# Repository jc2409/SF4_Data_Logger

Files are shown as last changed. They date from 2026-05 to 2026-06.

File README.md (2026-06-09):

# SF4 Smart Guitar Amp

SF4 is a hybrid guitar-effect amplifier built around a real analog input/output
path, an Arduino Uno DSP firmware, and a browser-based host app. The system lets
a player control the amp manually or ask for a sound in natural language; the host
turns that request into validated firmware parameters and sends them to the board.

The current implementation has three working layers:

1. Analog hardware for guitar-level signal conditioning, optical gain control, ADC
   input conditioning, and PWM audio reconstruction.
2. Arduino firmware for real-time DSP, automatic gain control, serial commands, and
   telemetry.
3. A FastAPI + React web app with sliders, live telemetry, tuner display, OpenAI chat,
   and Whisper-based voice input.

See [docs/SF4_Interim_Report.pdf](docs/SF4_Interim_Report.pdf) for the project report
context. The current host setup details live in [src/host/README.md](src/host/README.md).

## System Overview

```text
Guitar
  -> analog input buffer and 2.5 V bias
  -> optically controlled analog gain stage
  -> anti-aliasing low-pass filter
  -> Arduino A0 ADC
  -> Uno DSP firmware
  -> 62.5 kHz PWM audio on pin 10
  -> two-stage RC reconstruction filter and output coupling
  -> amp / line input / high-impedance headphones

Browser UI
  -> FastAPI host
  -> serial P frames to Arduino
  <- T telemetry frames from Arduino
  -> OpenAI chat and Whisper STT when enabled
```

The host falls back to a mock serial link when no board is connected, so the web app
and LLM/voice flow can still be demonstrated without hardware.

## Final Analog Circuit

The analog path is designed for a single 5 V system while preserving the AC guitar
signal around a 2.5 V virtual ground.

**Input and biasing**

- The guitar enters a high-impedance buffered input so passive pickups are not loaded.
- The signal is AC-coupled, then biased at about 2.5 V so the Arduino ADC can read the
  waveform inside its 0-5 V range.
- A buffered 2.5 V reference is used as the analog midpoint for the signal chain.

**Optical variable gain stage**

- The firmware drives an optocoupler LED from PWM pin 9 / OC1A.
- The optocoupler LDR changes the analog gain without putting a noisy digital control
  signal directly into the audio path.
- In automatic mode, firmware rides this gain gently based on measured output peak:
  loud signals are attenuated, quiet played signals are boosted, and silence drifts
  back to the resting gain.

**ADC conditioning**

- The post-gain audio is low-pass filtered before A0 to reduce content above the ADC
  Nyquist frequency.
- The firmware samples A0 at about 9.6 kHz, so the practical audio bandwidth is guitar
  focused rather than hi-fi full range.

**PWM audio output**

- The Arduino outputs processed audio as 8-bit Fast PWM on pin 10 / OC1B at 62.5 kHz.
- The final reconstruction filter is two passive RC low-pass stages with a buffer between
  them: 2.2 kOhm + 15 nF per stage, giving a corner near 4.8 kHz per pole.
- The buffer-between-poles topology is intentional. It avoids the high-frequency carrier
  feedthrough and slew problems seen with a slow-op-amp Sallen-Key attempt.
- The output is AC-coupled through a 10 uF capacitor with a 100 kOhm pulldown, removing
  the 2.5 V bias while keeping the guitar low end intact.
- The output is intended for a high-impedance line/aux input or similar load, not for
  directly driving a low-impedance speaker.

The PWM output-stage debugging and component choices are documented in
[src/PWM_Audio_Passthrough/DESIGN_NOTES.md](src/PWM_Audio_Passthrough/DESIGN_NOTES.md).

## Firmware

The current firmware is [src/DSP_Pipeline/DSP_Pipeline.ino](src/DSP_Pipeline/DSP_Pipeline.ino).
It targets an Arduino Uno R3 / ATmega328P.

**Timing and I/O**

- ADC input: A0, free-running, prescaler 128, about 9.6 kHz sample rate.
- Audio output: Timer1 8-bit Fast PWM on pin 10 / OC1B, 62.5 kHz carrier.
- VGA output: Timer1 PWM on pin 9 / OC1A, 0-255 duty value.
- Serial: 115200 baud.
- Audio processing runs in the `ADC_vect` interrupt, one sample at a time.

**Effects**

The firmware runs exactly one effect mode at a time:

| ID | Effect | Implemented behavior |
| --- | --- | --- |
| `0` | Clean | Transparent passthrough. |
| `1` | Overdrive | Pre-gain followed by hard clipping; `drive` range 1-511. |
| `2` | Delay | Single circular-buffer echo, up to 512 samples, about 53 ms at 9.6 kHz. |
| `3` | Chorus | Triangle-LFO modulated short delay with 50/50 dry/wet mix. |
| `4` | Reverb | Ten-tap feedback network; feedback should stay below about 205 for stability. |
| `5` | Tuner | Clean passthrough while the main loop runs AMDF pitch detection. |

The shared audio buffer is 512 `int8_t` samples. Delay, chorus, reverb, and tuner all
reuse that memory so the firmware fits within the Uno SRAM budget.

**Serial control protocol**

The host sends an atomic all-parameters frame:

```text
P,<effect>,<drive>,<delayLen>,<feedback>,<mix>,<depth>,<rate>,<autoVGA>,<gain>
```

Ranges enforced by the firmware and host models:

| Field | Range | Meaning |
| --- | --- | --- |
| `effect` | 0-5 | Clean, overdrive, delay, chorus, reverb, tuner. |
| `drive` | 1-511 | Overdrive gain/clipping intensity. |
| `delayLen` | 1-512 | Delay tap distance in samples. |
| `feedback` | 0-255 | Delay repeats or reverb decay. |
| `mix` | 0-255 | Wet level for delay/reverb. |
| `depth` | 1-48 | Chorus modulation depth in samples. |
| `rate` | 1-20 | Chorus LFO phase increment. |
| `autoVGA` | 0 or 1 | Enable automatic analog gain control. |
| `gain` | -1 or 0-255 | `-1` keeps/uses auto mode; 0-255 sets manual VGA PWM. |

The board reports telemetry every 100 ms:

```text
T,<effect>,<peak>,<vga>,<clip>,<rxErr>,<freqDeciHz>
```

`freqDeciHz` is only nonzero in tuner mode and is reported as Hz x 10. The host turns
this into the tuner display against standard guitar tuning.

More firmware-specific notes are in [src/DSP_Pipeline/README.md](src/DSP_Pipeline/README.md).

## Web App

The web app lives in [src/host](src/host). It is a single FastAPI backend serving a
React/Vite frontend.

**Backend responsibilities**

- Own the real `SF4Link` serial connection, or use `MockLink` when hardware is absent.
- Keep the authoritative `AmpParams` state.
- Validate and clamp all values before they reach the firmware.
- Serve `GET /api/state`, `POST /api/params`, `POST /api/chat`, `POST /api/transcribe`,
  and `GET /api/telemetry`.
- Load `.env` for serial port, OpenAI proxy, CA bundle, model names, and server host/port.

**Frontend responsibilities**

- Manual amp controls for effect selection and the relevant parameters.
- Live telemetry and connection state.
- Tuner UI driven by firmware pitch telemetry.
- Chat panel for natural-language tone requests.
- Voice input flow using the wake phrase `hey amp`, browser microphone capture, Whisper
  transcription, and then the same chat/tone path as typed messages.

**Tone engine**

- OpenAI is the default provider when `OPENAI_API_KEY` is set.
- `OPENAI_BASE_URL` supports enterprise proxy routing, including the Arm proxy URL.
- `OPENAI_CA_BUNDLE` lets Python trust the enterprise TLS certificate without disabling
  verification.
- `OPENAI_CHAT_MODEL` currently defaults to `gpt-5.5`; change it in `.env` if the proxy
  reports no regional capacity for that model.
- Anthropic remains available as a fallback with `SF4_LLM_PROVIDER=anthropic` and
  `ANTHROPIC_API_KEY`.

The LLM is not allowed to send arbitrary firmware strings. It can only call the structured
`set_amp_params` tool, and those values are validated by the host before the serial frame
is emitted.

## Running The Web App

From the repository root:

```bash
cd src/host
make env
# edit .env: set OPENAI_API_KEY, OPENAI_BASE_URL if required, and SF4_PORT if needed
make install
make run
```

Then open `http://127.0.0.1:8000`.

Useful setup commands:

```bash
make port          # list serial devices and mark likely Arduino ports
make set-port      # write detected board to .env as SF4_PORT=...
make serial-perms  # temporary Linux permission fix for the selected SF4_PORT
make doctor        # print local Python/Node/npm/OpenAI/SF4_PORT status
make web-dev       # frontend hot reload on :5173 while make run serves the API
make flash         # compile/upload firmware with arduino-cli
```

Dependencies and configuration are documented in [src/host/README.md](src/host/README.md).
The Python dependency lists are [src/host/requirements.txt](src/host/requirements.txt) and
[src/host/pyproject.toml](src/host/pyproject.toml); frontend dependencies are in
`src/host/web/package.json` and `src/host/web/package-lock.json`.

## Repository Layout

```text
docs/                         project handouts, order sheet, interim report
src/DSP_Pipeline/             current Arduino DSP firmware and firmware README
src/PWM_Audio_Passthrough/    PWM output-stage prototype and final design notes
src/host/                     FastAPI backend, React frontend, Makefile, host docs
schematics/                   analog design and LTSpice material
```

## Current Limitations

- Audio quality is constrained by the Arduino Uno ADC rate, 8-bit PWM output, SRAM, and
  simple reconstruction filter. This is a working guitar-effect prototype, not a studio
  audio interface.
- Only one firmware effect runs at a time.
- The output stage expects a high-impedance input/load.
- Voice transcription and chat depend on the selected OpenAI model being available through
  the configured proxy and VPN policy.

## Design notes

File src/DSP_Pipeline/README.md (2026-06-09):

# SF4 Real-Time Guitar DSP Pipeline — Firmware

Arduino Uno R3 (ATmega328P) firmware implementing a real-time, **selectable
multi-effect** guitar DSP — **Clean / Overdrive / Delay / Chorus / Reverb** — plus
a **Tuner** mode that detects the played string's pitch, all with a serial command
interface for live parameter control.

Sketch: [`DSP_Pipeline.ino`](DSP_Pipeline.ino)

> **Note:** an earlier version of this firmware (and this README) ran a *cumulative*
> `Clip → Biquad EQ → Delay` pipeline driven by an `S,...` frame at 19230 Hz. That is
> obsolete. The current firmware selects **one** effect at a time and runs the ADC at
> **~9615 Hz**. The host software (`../host/`) targets this current protocol.

---

## Signal path

```
guitar (biased 2.5 V) ─▶ A0 ─▶ ADC (free-running, 10-bit, ~9.615 kHz, prescaler 128)
                                  │
                                  ▼  ISR(ADC_vect)   ← one DSP tick per sample
                    one of: Clean | Overdrive | Delay | Chorus | Reverb
                                  │
                                  ▼
                    OCR1B (8-bit, 62.5 kHz Fast PWM, pin 10)
                                  │
                                  ▼
                    RC reconstruction filter ─▶ analog audio out
```

- **Input**: guitar AC-coupled and biased to 2.5 V on A0; ADC reads 0..1023 (512 = silence).
- **Output**: pin 10 (OC1B), 8-bit Fast PWM, 62.5 kHz carrier, smoothed by an external RC filter.
- **Optocoupler**: pin 9 (OC1A), same Timer1, sets the analog VGA gain via the LED/LDR.
- **Sample rate**: ADC prescaler 128 → ~9615 Hz (Nyquist 4.8 kHz, matching the anti-alias LPF).
  Delay/reverb taps are `t = samples / 9615 Hz`; the 512-sample buffer holds ~53 ms.

---

## Effects

All processing is **fixed-point** (no float in the ISR). Samples are carried as
signed values centred on 0 (range −512..+511). **One effect is active at a time**
(selected with `e`); switching effects clears the audio ring buffer.

| ID | Effect | What it does | Parameters |
|----|---|---|---|
| 0 | **Clean** | Transparent passthrough | — |
| 1 | **Overdrive** | Pre-amplify then hard-clip | `thresh` 1..511 (drive: 16=breakup, 180=rock, 480=metal) |
| 2 | **Delay** | Single echo with feedback (~53 ms max) | `delayLen` 1..512, `feedback` 0..255, `mix` 0..255 |
| 3 | **Chorus** | Triangle-LFO modulated short delay, 50/50 dry/wet | `depth` 1..48, `rate` 1..20 |
| 4 | **Reverb** | Ten-tap feedback network | `feedback` 0..255 (keep < 205), `mix` 0..255 |
| 5 | **Tuner** | Clean passthrough + fundamental-pitch detection (reported via telemetry) | — |

**Delay/reverb timing**: `t = samples / 9615 Hz`. The 512-sample `int8` line holds ~53 ms.

### Tuner

Selecting **Tuner** (effect 5) passes the signal through clean while detecting the
played string's fundamental frequency and reporting it in the `freq` telemetry
field (deci-Hz; `0` = no pitch). The host UI shows the detected pitch against the
six standard-tuning strings (E2 A2 D3 G3 B3 E4) with a flat↔sharp cents needle.

- **Method**: **AMDF** (Average Magnitude Difference Function) over the audio ring
  buffer, searching lags ~24..128 samples (≈75–400 Hz). The deepest dip is the
  period; **parabolic interpolation** around it recovers sub-sample resolution —
  essential for the high strings, where one whole-sample lag step is tens of cents
  at 9615 Hz. A peak-amplitude gate suppresses readings on silence.
- **Where it runs**: in `loop()` (every ~150 ms), **not** the ISR, and only while
  effect 5 is active — so it costs nothing in the other modes. It works on a frozen
  copy of the most recent samples, since the ISR keeps overwriting the live ring
  during the (tens-of-ms) computation.

---

## Serial command interface

`115200 baud`, one command per line. The parser buffers a full line then parses
it (robust to `\n` / `\r\n` / no line ending).

| Command | Example | Effect |
|---|---|---|
| `e<0..5>` | `e1` | Select effect (0=clean 1=overdrive 2=delay 3=chorus 4=reverb 5=tuner) |
| `c<1..511>` | `c180` | Overdrive drive (thresh) |
| `d<1..512>` | `d400` | Delay length in samples |
| `f<0..255>` | `f190` | Delay/reverb feedback / decay |
| `m<0..255>` | `m220` | Delay/reverb wet mix |
| `r<1..48>` | `r24` | Chorus depth |
| `s<1..20>` | `s8` | Chorus LFO rate |
| `v<0\|1>` | `v1` | Auto-VGA on/off |
| `g<0..255>` | `g20` | Manual VGA gain (OCR1A); turns auto-VGA off |
| `x` | `x` | Bypass (clean passthrough) |
| `P,...` | `P,1,180,400,190,220,24,8,1,-1` | Atomic set-all frame (host link) |

The single-letter commands are for manual testing; the host uses the `P` frame.

> **Note**: a delay/echo is only audible on *transient* material (real guitar,
> plucks, music). On a steady sine it just produces inaudible comb filtering.

## Two-way host protocol (MCU ↔ PC)

Structured parameters in, status telemetry out. The host applies a whole preset
atomically with one `P` frame and reads `T` telemetry back:

```
PC -> MCU : P,<effect>,<drive>,<delayLen>,<feedback>,<mix>,<depth>,<rate>,<autoVGA>,<gain>\n
MCU -> PC : T,<effect>,<peak>,<vga>,<clip>,<rxErr>,<freq>\n      (emitted ~10 Hz)
```

- **`P` frame** — sets the entire parameter bank in one `cli/sei` section (no
  transient old+new mix), clearing the audio buffer on effect change. `gain` field
  `< 0` leaves the VGA untouched and honours the `autoVGA` flag; `>= 0` sets a manual
  gain and turns auto-VGA off. Malformed frames are rejected and counted in `rxErr`.
- **`T` telemetry** — `effect` (active effect ID), `peak` (max |output| since last
  report — a VU meter), `vga` (current `OCR1A`), `clip` (clipped since last report),
  `rxErr` (malformed-frame count), `freq` (detected fundamental in **deci-Hz** —
  Hz×10 — in tuner mode, else `0`).
  > The `freq` field is appended; the host parser accepts both the 6-field
  > (pre-tuner) and 7-field frames, so older firmware still parses.

### Host software

The full interface is the **web app** in [`../host/`](../host/) (FastAPI + LLM tone
engine + browser dashboard). For bench testing without a browser:

```bash
cd ../host && uv sync          # or: pip install -e .
python sf4_serial.py --demo overdrive
python sf4_serial.py --effect reverb --feedback 190 --mix 220
```

It builds a validated `AmpParams`, serialises the `P` frame, sends it, then prints
parsed `T` telemetry as a live meter.

---

## Architecture / timing

- **Timer1** — Mode 5, 8-bit Fast PWM, no prescaler → **62.5 kHz** carrier on
  OC1A (pin 9) and OC1B (pin 10). Pure hardware; **no overflow ISR**.
- **ADC** — free-running, `/128` prescaler → ~**9615 Hz** sample rate, with the
  conversion-complete interrupt enabled (Nyquist 4.8 kHz, matching the anti-alias LPF).
- **`ISR(ADC_vect)`** — the single DSP tick: reads `ADC`, runs `processEffect`,
  writes `OCR1B = result >> 2` (10-bit → 8-bit). Fires once per sample (~9615 Hz).
  Reading `ADC` clears `ADIF` and the ADC auto-restarts, so no flag handling is needed.
- `OCR1B` is **double-buffered** by the PWM hardware (latches at carrier BOTTOM),
  so updating it at 9615 Hz while the carrier runs at 62.5 kHz is glitch-free.
- **Parameter bank** — one `volatile Params` struct (`P`). `loop()` updates it
  atomically inside `noInterrupts()/interrupts()` (field-wise copies, because a
  `volatile` struct can't use the implicit copy ctor), so the ISR never reads a
  half-written parameter set.

---

## Testing & operation notes

### Reading the telemetry (`T,effect,peak,vga,clip,rxErr,freq`)
- **`effect`** — active effect ID (0–5).
- **`peak`** — loudest **post-effect** sample since the last report (~100 ms), as a
  centred magnitude. This is a live VU/level meter; it wobbles ±1 on a steady signal
  (normal). It reflects what the listener actually hears (the AGC rides off it), so
  it tracks the output, not the raw input.
- **`vga`** — current `OCR1A` (the optocoupler LED duty / analog gain); static until
  changed or moved by auto-VGA.
- **`clip`** — 1 if the signal hit the clip threshold in that window, else 0.
- **`rxErr`** — malformed-frame count; should stay 0 (link health).
- **`freq`** — detected fundamental in **deci-Hz** (Hz×10) in tuner mode, else `0`.

### Startup transient is expected (and repeats every run)
Opening the serial port toggles **DTR, which hardware-resets the Uno** — so every
`sf4_serial.py` run reboots the board from scratch. At boot `OCR1A = 20`
(resting VGA gain), then the first host `P` frame confirms auto-VGA mode; the optocoupler LDR
settles slowly (tens–hundreds of ms), so `peak` shows a brief spike that decays
(e.g. `197 → 6`). Harmless — it's the analog gain settling, not a glitch. Ignore
the first few telemetry lines, or add gain smoothing in firmware to remove it.

### What a sine-wave input can test
| Stage | Sine test | Method |
|---|---|---|
| Passthrough | ✅ | `x`; output = input, biased 2.5 V |
| Clipping (overdrive) | ✅ | drive above threshold → flat-topped wave + odd harmonics |
| Aliasing | ✅ | feed f > Nyquist (4.8 kHz) → watch it fold back |
| Delay comb | ✅ | sweep → notches every `FS/d` Hz |
| Chorus sweep | ✅ | slow LFO → pitch/comb notches drift up and down |
| Delay/reverb *echo* | ❌ | needs transients (real guitar / music) |
| Tuner | ✅ | feed a known tone → check `freq` (deci-Hz) telemetry |

### Signal levels (real guitar vs the VGA)
A raw passive guitar is weak and dynamic (~0.1–0.7 Vpp typical, peaks to ~1–1.5 Vpp
on hard strums, decaying fast) — it does **not** sit at line level. The optocoupler
**VGA (gain) is what boosts it** up to where `peak` crosses the clip threshold, so
`gain` (drive) + `clip_threshold` together behave like a pedal's Drive knob. On the
bench, ~1 Vpp from the generator is a *test* level to force clipping. Distortion is
naturally touch-sensitive: loud attack clips, decaying note cleans up.

---

## Implementation notes

### DSP runs in `ADC_vect`, not a timer ISR
The single DSP tick lives in **`ISR(ADC_vect)`** (~9615 Hz): it reads `ADC`, runs
`processEffect`, and writes `OCR1B`. The Timer1 overflow interrupt is left disabled
(`TIMSK1 = 0`) — the PWM carrier is pure hardware. Driving the DSP from the ADC
interrupt means it fires exactly once per sample, with no wasted firings.

### Atomic parameters from a `volatile` struct
`Params np = P;` / `P = np;` don't compile for a `volatile` struct, so `loop()`
copies fields one at a time inside `noInterrupts()/interrupts()`. This both satisfies
the compiler and makes parameter updates atomic — the ISR never sees a half-written
mix of old and new values, and switching effects clears the audio ring buffer.

### Robust serial parsing
The command parser **buffers a full line** then parses it with `atol` / `sscanf`,
tolerant of `\n`, `\r\n`, or no line ending. (An earlier `Serial.parseInt()` version
mis-read leftover `\r`/`\n` as `0`, e.g. `f160` → `feedback = 0`.) The board runs at
**115200 baud**; because the DSP no longer sits in a 62.5 kHz timer ISR, the USART RX
interrupt is serviced in time and there is no RX overrun.

### Two-way protocol (MCU ↔ PC)
The host applies a whole preset atomically with one **`P` frame** and reads **`T`
telemetry** back at ~10 Hz (`effect, peak, vga, clip, rxErr, freq`). The ISR tracks
`g_peak` / `g_clip` / `g_freqDeciHz`; `loop()` emits via `millis()`. The full
host-side link is the FastAPI web app in [`../host/`](../host/); `sf4_serial.py` is a
standalone CLI for bench testing the same `P`/`T` protocol.

---

## Recommended analog output stage

The PWM output needs an external reconstruction filter + buffer before any
external device. Drives high-impedance line inputs (Echo line-in, Sennheiser
Momentum 4 powered aux) directly — **no power amp needed**.

```
pin 10 ─[2-pole RC LPF: 2.2k / 15nF ×2]─ MCP6002 unity buffer ─ Rs 100Ω ─ Cout 10µF ─┬─ tip L ┐
                                                                                      ├─ tip R ┘ (tie, mono)
                                                                                     R 100k → GND
                                                                                      sleeve → GND
```

- **Use MCP6002** (rail-to-rail, single 5 V), **not** TL072 (needs ≥7 V).
- Because the MCP6002 is only 1 MHz GBW, **filter passively** (RC) and use the
  op-amp only as a buffer — do **not** put it in a Sallen-Key (it would leak the
  62.5 kHz carrier, like the LM358).
- Two RC poles give ~−40 dB at the carrier, removing the switching hash.
- `Cout` strips the 2.5 V DC bias; into a high-Z input the bass is preserved.

---

## Known limitations / potential issues

| Issue | Impact | Possible improvement |
|---|---|---|
| Hard-clip aliasing | Harsh "fizzy" distortion (folded harmonics) | Soft-clip lookup table; 2× oversampling |
| 8-bit PWM output | ~48 dB SNR; hiss on clean tones | Higher-res PWM; dithering |
| One effect at a time | No stacking (e.g. overdrive + delay) | Chain effects if CPU/SRAM allow |
| Delay/reverb ≤ ~53 ms | Slapback/short ambience, not long echo | External SRAM for a longer line |
| `int8` ring buffer | 2 LSBs dropped on stored samples | Wider buffer if SRAM allows |
| No parameter smoothing | Clicks on live LLM/host changes | Ramp parameters over a few ms |
| Free-running ADC jitter | Minor sample-timing noise | Timer-triggered ADC (needs a free timer) |
| 16 MHz AVR ceiling | Limited DSP headroom overall | Faster MCU for advanced effects |

---

## Status

Working lo-fi multi-effect demonstrator: selectable Clean / Overdrive / Delay /
Chorus / Reverb plus an AMDF Tuner, with live serial control **and a two-way MCU↔PC
link** (`P` params in, `T` telemetry out, at 115200). The FastAPI web app in
[`../host/`](../host/) drives this protocol from the browser, manual controls, and the
LLM tone engine; `sf4_serial.py` exercises the same link from the command line.

### Suggested next steps
- DSP quality: soft-clip lookup table (reduce overdrive aliasing), parameter/gain
  smoothing to remove clicks on live host changes.
- Longer delay/reverb via external SRAM, beyond the ~53 ms on-chip `int8` line.
- Build the MCP6002 analog output stage (above) for clean line-out.

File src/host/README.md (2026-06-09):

# SF4 Host - Backend, Voice UI, and Tone Engine

This directory contains the desktop/web host for the SF4 smart guitar amp. One
FastAPI process owns the serial link to the Arduino, keeps the authoritative amp
state, runs the OpenAI-first tone engine, serves the React dashboard, and exposes
JSON/SSE APIs for manual control, chat, voice transcription, and telemetry.

## Layout

```text
app/
  main.py         FastAPI app: /api/* endpoints, static UI serving, app lifetime
  models.py       AmpParams, telemetry, chat schemas, firmware value ranges
  serial_link.py  SF4Link hardware bridge, MockLink fallback, port autodetect
  tone_engine.py  OpenAI/Anthropic tone engine with set_amp_params tool use
  openai_client.py OpenAI client setup for API key, proxy URL, and CA bundle
  devtools.py     Makefile helpers for serial-port detection and config checks
  static/         built React UI generated by make web-build, gitignored
web/              React + Vite frontend source
sf4_serial.py     CLI bench-test tool for sending P frames and reading telemetry
Makefile          setup, build, run, serial, and firmware automation
requirements.txt  pip dependency list, kept in sync with pyproject.toml
pyproject.toml    Python project metadata and dependencies
.env.example      local configuration template; copy to .env
```

The React source lives in `web/`. `make web-build` compiles it into `app/static/`,
which FastAPI serves at `http://127.0.0.1:8000` by default.

## Quick Start

```bash
cd src/host
make env
# edit .env and set OPENAI_API_KEY, OPENAI_BASE_URL if using the Arm proxy,
# OPENAI_CA_BUNDLE if your machine needs the company CA, and SF4_PORT if needed
make install
make run
```

Open `http://127.0.0.1:8000`.

`make run` also installs Python dependencies and builds the UI on first run if the
built frontend is missing. Use `Ctrl+C` to stop Uvicorn.

## Make Targets

| Target | Purpose |
| --- | --- |
| `make help` | Print the available commands. |
| `make env` | Create `.env` from `.env.example` if it does not exist. |
| `make py-install` | Install backend dependencies with `uv sync` when `uv` is available, otherwise create `.venv` and run `pip install -r requirements.txt`. |
| `make web-install` | Install frontend dependencies with `npm ci --include=dev --no-audit --no-fund --progress=false`. |
| `make web-build` | Build the React/Vite UI into `app/static/`. |
| `make install` | Run backend install, frontend install, and frontend build. |
| `make run` | Start FastAPI on `HOST:PORT`, building the UI first if missing. |
| `make dev` | Same as `make run`, but with Uvicorn `--reload`. |
| `make web-dev` | Start Vite hot reload on port 5173; `/api` is proxied to FastAPI on port 8000. |
| `make port` | List detected serial ports and mark likely Arduino ports with `*`. |
| `make set-port` | Write the first likely Arduino port into `.env` as `SF4_PORT=...`. |
| `make serial-perms` | Temporarily run `sudo chmod a+rw $(SF4_PORT)` if Linux denies access to the board. |
| `make doctor` | Print Python, Node, npm, host URL, serial setting, and whether OpenAI settings are present. |
| `make cli ARGS="--demo overdrive"` | Test the serial link without the browser. |
| `make flash` | Compile and upload `../DSP_Pipeline` with `arduino-cli`. |
| `make clean` | Remove `.venv`, Python caches, and built UI output. |

For frontend-only development, use two terminals:

```bash
make run        # terminal A: FastAPI on :8000
make web-dev    # terminal B: Vite on :5173 with /api proxying
```

## Dependencies

System tools:

- Python 3.11 or newer.
- Node.js and npm for the React/Vite frontend.
- `arduino-cli` only if you want `make flash` to compile and upload firmware.
- Linux serial access to the board, either through group membership or `make serial-perms`.

Python packages are declared in both `requirements.txt` and `pyproject.toml`:

- `fastapi`, `uvicorn[standard]`: web server and API runtime.
- `pyserial`: USB serial link to the Arduino.
- `openai`, `httpx`: OpenAI chat/STT client, enterprise proxy, and CA-bundle support.
- `anthropic`: optional fallback provider.
- `pydantic`: API and firmware parameter validation.
- `python-dotenv`: `.env` loading.
- `python-multipart`: browser audio upload support for `/api/transcribe`.

Frontend packages are managed by `web/package.json` and `web/package-lock.json`.
Use `make web-install` or `make install`; do not use `npm install --omit=dev`, because
Vite is a dev dependency required for building.

## Configuration

Copy `.env.example` to `.env` with `make env`. `.env` is gitignored and should hold
machine-specific settings and API keys.

| Variable | Default | Meaning |
| --- | --- | --- |
| `SF4_LLM_PROVIDER` | `openai` | Tone engine provider: `openai` or `anthropic`. |
| `OPENAI_API_KEY` | blank | Required for OpenAI chat and Whisper transcription. |
| `OPENAI_CHAT_MODEL` | `gpt-5.5` | Chat model used for tone generation. Change this if the proxy has no capacity for that model. |
| `OPENAI_BASE_URL` | OpenAI default | Set to the enterprise proxy URL, for example `https://openai-api-proxy.geo.arm.com/api/providers/openai/v1`. |
| `OPENAI_CA_BUNDLE` | Arm root CA path | Optional CA bundle path for enterprise TLS verification. |
| `OPENAI_TRANSCRIBE_MODEL` | `whisper-1` | Speech-to-text model used by `/api/transcribe`. |
| `ANTHROPIC_API_KEY` | blank | Optional fallback when `SF4_LLM_PROVIDER=anthropic`. |
| `SF4_MODEL` | `claude-haiku-4-5` | Anthropic model name for the fallback provider. |
| `SF4_PORT` | auto-detect | Serial device, for example `/dev/ttyACM0`. Use `make port` or `make set-port`. |
| `HOST` / `PORT` | `127.0.0.1` / `8000` | Uvicorn bind address used by `make run` and `make dev`. |

For the Arm enterprise OpenAI proxy, the relevant `.env` entries are usually:

```bash
OPENAI_API_KEY=your_key_here
OPENAI_BASE_URL=https://openai-api-proxy.geo.arm.com/api/providers/openai/v1
OPENAI_CA_BUNDLE=/usr/local/share/ca-certificates/ARM-Enterprise-PKI-Root-CA.crt
OPENAI_CHAT_MODEL=gpt-5.5
OPENAI_TRANSCRIBE_MODEL=whisper-1
```

If you see `data_residency_mismatch` or `No available capacity`, the proxy rejected the
selected model in that region. Change `OPENAI_CHAT_MODEL` to a model that your proxy
supports and restart `make run`.

## API

| Endpoint | Purpose |
| --- | --- |
| `GET /api/state` | Current amp parameters, serialized with the effect name. |
| `POST /api/params` | Apply a full manual `AmpParams` update. |
| `POST /api/chat` | Run one tone-engine turn; may call `set_amp_params` and update the board. |
| `POST /api/transcribe` | Upload browser audio and return Whisper text. |
| `GET /api/telemetry` | Server-Sent Events stream of board telemetry at about 10 Hz. |

The app falls back to `MockLink` when no Arduino is available, so the UI, chat, and
voice flow can be tested without hardware. Manual changes still update the shared app
state, but no serial frames are sent to a board.

## Troubleshooting

- `vite: not found`: run `make web-install` or `make install`. If npm used omitted dev dependencies, run `npm --prefix web ci --include=dev --no-audit --no-fund --progress=false`.
- Npm hangs on VPN: check whether company VPN/proxy rules block `registry.npmjs.org`; disconnecting VPN or configuring npm proxy may be required.
- `Permission denied: /dev/ttyACM0`: run `make set-port`, then `make serial-perms`, or add your user to the Linux dialout group and log out/in.
- `Chat is unavailable`: set `OPENAI_API_KEY` or configure the Anthropic fallback, then restart the server.
- `Transcription error`: check `OPENAI_API_KEY`, `OPENAI_BASE_URL`, `OPENAI_CA_BUNDLE`, and VPN/proxy connectivity.
- Browser says microphone denied: allow microphone access for `http://127.0.0.1:8000` in the browser site settings, then reload.

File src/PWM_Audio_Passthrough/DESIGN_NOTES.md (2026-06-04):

# PWM Audio Passthrough — Design & Debug Notes

A record of the debugging session that took the PWM audio output from "looks like
raw PWM on the scope" to a clean, full-range guitar signal. Covers the filter
diagnosis, the component-value fixes, and the firmware change to a 62.5 kHz carrier.

---

## 1. The system

- **Arduino Uno R3**, guitar signal biased to 2.5 V into **A0** (ADC 0..1023, 512 ≈ silence).
- **Timer1 Fast PWM** drives two independent outputs:
  - **Pin 10 (OC1B)** → audio, through a low-pass filter → audio jack.
  - **Pin 9 (OC1A)** → optocoupler LED (VGA gain stage), set over serial.
- Audio recovered by averaging the PWM (low-pass) then AC-coupling out (high-pass).

Output analog chain (KiCad): `pin 10 → R12 → C7 (low-pass) → LM358 (U2B) → C8 → R13 (high-pass) → AudioJack`.

---

## 2. The symptom

On the PicoScope:
- **Blue (A)** = analog input at A0: a clean sine (300/600/800 Hz test tones), biased at 2.5 V.
- **Red (B)** = "recovered" output: a dense band of pulses, **cycle time 64.00 µs → 15.625 kHz**.

The red trace never looked like the blue sine. The user asked why.

### Why red ≠ blue (the concept)
The raw PWM is a **two-level carrier** (≈0 V or ≈5 V) switching at 15.625 kHz. The
audio is encoded in the **duty cycle / pulse width**, not the instantaneous voltage:

```
blue high (3.5V)  ->  OCR1B large  ->  pulses WIDE  (more time at 5V)
blue low  (2.0V)  ->  OCR1B small  ->  pulses NARROW (more time at 0V)
```

You recover the sine by taking the **running average** of the PWM — which is exactly
what the RC low-pass does. So red ≠ blue *before* the filter is expected and correct.

---

## 3. Root cause #1 — the low-pass filter wasn't filtering

A low-pass needs **both** the series resistor **and** the shunt cap to ground. R12
alone does nothing (the op-amp input is high-impedance, so almost no drop across R12).
C7 is the part that averages the pulses.

The cutoff:

$$f_c = \frac{1}{2\pi R C}$$

The board had **R12 = 1k** and **C7 marked `103` = 10 nF** (NOT the assumed 220 nF):

$$f_c = \frac{1}{2\pi \cdot 1000 \cdot 10\text{n}} \approx 15.9\ \text{kHz}$$

That sits **right on top of the 15.625 kHz carrier** → only −3 dB attenuation → the
carrier passes straight through. Time-constant view: `τ = R12·C7 = 10 µs`, but the
PWM period is `64 µs`, so the cap fully tracks each pulse instead of averaging.

### Capacitor code reminder (value in picofarads)
| Code | Value | Notes |
|---|---|---|
| `103` | 10 nF | what was in C7 (wrong — too small) |
| `104` | 100 nF | fc ≈ 1.6 kHz |
| `224` | 220 nF | fc ≈ 723 Hz |

> The user *thought* 220 nF was in C7, but `224` (220 nF) was actually in **C8**
> (the output coupling cap). So C7 = 10 nF (low-pass), C8 = 220 nF (coupling) —
> swapped roles.

### Fix
Put a real **220 nF (`224`)** in C7. With R12 = 1k → fc ≈ 723 Hz, carrier ≈ −27 dB.
The red trace then collapsed into a recognizable sine (with some residual ripple).

---

## 4. Root cause #2 — single RC can't cover guitar range AND reject the carrier

After the 220 nF fix, the recovered sine still had **high-frequency ripple** (residual
15.6 kHz carrier). The fundamental problem:

- **Guitar needs audio out to ~5 kHz** (fundamentals reach ~1.3 kHz; harmonics/tone to ~5–6 kHz).
- **Carrier is at 15.6 kHz** — only **~3× above** the audio top.
- A single-pole RC is just 20 dB/decade. To kill a carrier only 3× away you must drop
  fc so low it also eats the guitar harmonics. **You can't win with a filter alone.**

Single-pole trade-off table (R12 = 1k):

| C7 | Code | fc | Carrier rejection | Audio bandwidth |
|----|---|----|----|----|
| 220 nF | `224` | 723 Hz | −27 dB (~150 mV ripple) | ~720 Hz |
| 470 nF | `474` | 339 Hz | −33 dB | ~340 Hz (too dull) |
| 1 µF | `105` | 159 Hz | −40 dB | bass only ❌ |

---

## 5. The Sallen-Key attempt — and why it made things WORSE

We tried reusing the LM358 (U2B) as a **unity-gain Sallen-Key 2nd-order low-pass**
(Ra=Rb=2.2k, Ca=47 nF, Cb=22 nF). Result: **far worse** — big slew spikes,
channel over-range, and the dominant output frequency measured **~14.3 kHz** (carrier
feeding straight through).

Two reasons:

1. **LM358 is too slow.** ~1 MHz GBW, slew rate ~0.3 V/µs. At 15.6 kHz it has almost
   no loop gain and **slew-limits on the sharp PWM edges** → big spikes.
2. **Sallen-Key has inherent HF feedthrough.** The feedback cap **Ca connects the
   input-side node directly to the output**. At the carrier Ca ≈ 217 Ω (near short),
   so the raw PWM couples *around* the op-amp to the output. Above fc the rejection
   hits a floor instead of improving — and a slow op-amp makes it much worse.

**Lesson: do NOT use a Sallen-Key around the LM358 for this.** Either use a faster
op-amp (TL072 / MCP6002 rail-to-rail), or avoid the topology entirely.

---

## 6. The real fix — move the carrier away from the audio

The only way to have **full guitar bandwidth AND carrier rejection** is to stop
fighting the filter and **raise the PWM carrier** so a gentle filter at ~5 kHz works.

On a 16 MHz Uno, `carrier × resolution = 16 MHz`, so higher carrier = fewer bits:

| Carrier (Timer1 mode) | Resolution | Usable filter fc | Carrier rejection @ 5 kHz | Full guitar? |
|----|----|----|----|----|
| 15.6 kHz (10-bit, original) | 1024 | ~1.5 kHz max | — | ❌ loses harmonics |
| 31.25 kHz (9-bit) | 512 | 5 kHz | ~−32 dB (2nd order) | ✅ |
| **62.5 kHz (8-bit)** | 256 | **5 kHz** | **~−44 dB (2-stage RC)** | ✅✅ |

**Chosen: 8-bit / 62.5 kHz.** 256 levels (≈48 dB SNR) is fine for a guitar effect,
and the carrier is now ~12× above the audio top.

---

## 7. Recommended analog output chain (final)

Use the LM358 as a **plain buffer between two passive RC stages** (passive RC keeps
falling monotonically — no Sallen-Key feedthrough floor):

```
        ── LOW-PASS (sets top, kills carrier) ──    ── HIGH-PASS (sets bottom) ──
PWM ─R1─┬─→(+)LM358 buf─out─R2─┬─→ C8 ──┬──→ jack
        C1                     C2 nodeB  R13
        │                      │         │
       GND                    GND       GND
```

**Low-pass (per stage):**
- R1 = R2 = **2.2 kΩ**, C1 = C2 = **15 nF** (`153`) → fc ≈ 4.8 kHz each
- At 62.5 kHz: ~−22 dB per stage → **~−44 dB total**, monotonic, no spikes
- Passband flat to ~5 kHz → **full guitar tone preserved**
- **Buffer must sit BETWEEN the two stages** so they don't load each other (the
  op-amp's low output impedance isolates the poles).

**High-pass (strips the 2.5 V bias, sets the low end):**
- **C8 = 10 µF** (electrolytic) + R13 = 100 k → fc = 1/(2π·R13·C8) ≈ **0.16 Hz**
- Far below guitar low E (82 Hz) → **no bass loss**, with margin for low-Z loads.
- **Polarity matters:** `+` toward the op-amp side (~2.5 V), `−` toward the jack (0 V).

Resulting passband ≈ **0.16 Hz → 5 kHz** = full guitar range, carrier rejected.

### Capacitor dielectric note
For the filter caps, **film (polypropylene / polyester / polycarbonate)** beats Class II
ceramic (X7R/Y5V): tighter tolerance, no voltage-coefficient capacitance shift, and
lower distortion — so the filter corner stays put and the audio stays clean. (C8 stays
electrolytic for the bulk capacitance; it's outside the signal-shaping path.)

---

## 8. Firmware change (10-bit/15.6 kHz → 8-bit/62.5 kHz)

Edits applied to `PWM_Audio_Passthrough.ino`:

| Item | Before | After |
|---|---|---|
| Timer1 mode | Mode 7 (10-bit, `WGM11`+`WGM10`) | Mode 5 (8-bit, `WGM10` only) |
| Carrier | 16 MHz / 1024 = 15.625 kHz | 16 MHz / 256 = **62.5 kHz** |
| Audio scaling | `OCR1B = sample` (0–1023) | `OCR1B = sample >> 2` (0–255) |
| Mid-scale (silence) | `OCR1B = 512` | `OCR1B = 128` |
| Optocoupler range | `constrain(value, 0, 1023)` | `constrain(value, 0, 255)` |
| Serial help text | "0..1023" | "0..255" |

Key register block:

```c
// Timer1: Mode 5 = 8-bit Fast PWM (TOP = 0x00FF) on BOTH OC1A & OC1B
TCCR1A = (1 << COM1A1)   // non-inverting PWM on OC1A (pin 9, optocoupler)
       | (1 << COM1B1)   // non-inverting PWM on OC1B (pin 10, audio)
       | (1 << WGM10);   // WGM[11:10] = 01
TCCR1B = (1 << WGM12)    // WGM12 = 1 -> mode 5 (WGM[13:12] = 01)
       | (1 << CS10);    // no prescale -> 16 MHz / 256 = 62500 Hz

OCR1B  = 128;            // audio: mid-scale (2.5 V = silence)
OCR1A  = 0;             // optocoupler: LED off
```

ISR:

```c
ISR(TIMER1_OVF_vect) {        // fires at 62.5 kHz
  uint16_t sample = ADC;      // 0..1023 (512 = 2.5 V bias)
  // sample = processEffect(sample);   // DSP hook (passthrough for now)
  OCR1B = sample >> 2;        // scale 10-bit ADC -> 8-bit PWM (512 -> 128)
}
```

**Notes:**
- ADC unchanged (free-running 10-bit, ~19 kHz sample rate) — plenty for ~5 kHz audio.
  The PWM refreshes faster than the ADC updates, which is harmless.
- Optocoupler now takes **0–255**, not 0–1023 (update any host scripts).
- Don't use `analogWrite()` — the timer config has been replaced.

---

## 9. Quick reference — diagnostic checklist

If the recovered audio looks like raw PWM again:
1. **Is C7 actually the right value and soldered?** A series R with no shunt cap = no filter.
   Measure C7 with a multimeter on the capacitance range (or scope the op-amp + input).
2. **Decode the cap code:** `103` = 10 nF, `224` = 220 nF, `153` = 15 nF.
3. **Check fc vs carrier:** `fc = 1/(2π R C)` must be well below the carrier.
4. **Don't Sallen-Key the LM358** — passive RC + buffer instead.
5. **Carrier too close to audio?** Raise it in firmware (8-bit/62.5 kHz).
6. **Scope tip:** AC-couple channel B and pick a sensible range to see the ripple
   (the 2.5 V DC bias + spikes will over-range a tight DC window).

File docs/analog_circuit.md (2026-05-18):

# Analogue Circuit Design

## Overview

The analogue front-end conditions two independent input channels before they reach the Arduino ADC:

- **Channel A0 — Piezo sensor:** high-impedance voltage follower → active bandpass filter → gain stage → DC bias
- **Channel A1 — Thermistor:** voltage divider → passive RC low-pass filter

Both channels operate from the Arduino's 5V rail. A single LM358 dual op-amp IC handles both op-amp stages on the piezo channel. The thermistor channel needs no op-amp.

> **Op-amp choice:** Use the **LM358** (single-supply, 3–32V, from lab stock). Do **not** substitute the TL072 — its minimum supply is ±3.5V (7V total) and it will not operate from the Arduino's 5V rail.

If the SpO2 extension (Option A, BPW34 photodiode) is added later, a second LM358 is needed for the transimpedance amplifier — covered at the end of this document.

---

## Power Supply Architecture

```
Arduino 5V ──── polyfuse (200 mA) ──── breadboard +ve rail
                                             │
                             ├──── LM358 VCC (pin 8)
                             ├──── Voltage divider → 2.5V bias
                             └──── LED current sources

Arduino GND ──── breadboard −ve rail
                      │
                      └──── LM358 GND (pin 4), all signal grounds
```

Place a **100 nF ceramic decoupling capacitor** directly between pin 8 (VCC) and pin 4 (GND) of the LM358, physically adjacent to the IC. Without this, switching transients from the ATmega328P's internal clocking inject into the op-amp supply and appear as noise in the ADC readings.

---

## Channel A0 — Piezo Sensor Front-End

### Why the signal needs conditioning

The LDT1-028K is a capacitive (high-impedance) source. Its open-circuit voltage at breathing frequencies is typically 10–100 mV peak-to-peak, but the source impedance is in the tens of megaohms. Connecting it directly to the Arduino ADC causes severe attenuation because the ADC's effective input impedance is much lower than the source. The three-stage conditioning circuit solves this.

### Stage 1 — Voltage Follower (Buffer)

Op-amp A (LM358, pins 1, 2, 3), unity-gain configuration.

```
Piezo wire 1 ──── [R1: 1 MΩ] ──┬──── (+) in (pin 3)
                                │
                              [C1: 1 µF] ──── GND    ← HP corner: 0.16 Hz
                                │
Piezo wire 2 ──── GND       [R2: 1 MΩ] ──── GND    ← bias symmetry

(+) in (pin 3) ────────────────────────────────────── LM358A
(-) in (pin 2) ◄──────────────────── output (pin 1)  (unity gain feedback)
```

**R1 = 1 MΩ** forms a high-pass filter with C1: f_HP = 1/(2π × 1MΩ × 1µF) = **0.16 Hz**. This blocks slow DC drift from posture changes while passing the full breathing rate range (0.17–1.0 Hz = 10–60 br/min).

**R2 = 1 MΩ** on the non-inverting input matches the DC bias condition and minimises output offset due to input bias current.

**Why unity gain?** This stage is for impedance transformation only. The LM358 input impedance is ~1 GΩ — negligible loading on the piezo. The output impedance is < 1 Ω, able to drive the filter stage without signal loss.

### Stage 2 — Inverting Amplifier with Bandpass

Op-amp B (LM358, pins 5, 6, 7), inverting configuration.

```
Buffer output ──── [C2: 10 µF] ──── [R3: 2.2 kΩ] ──── (−) in (pin 6)
                                                              │
                                          [Rf: 100 kΩ] ──────┘──── output (pin 7)
                                                                        │
(+) in (pin 5) ──── 2.5V bias ──────────── [R_LP: 4.7 kΩ] ──────────┘
                                                │
                                            [C_LP: 100 nF] ──── GND
```

**C2 and R3 form the AC-coupling high-pass:** f_HP = 1/(2π × 2.2kΩ × 10µF) = **7.2 Hz** — this is intentionally aggressive; we only want breathing frequencies (< 2 Hz), not baseline wander from the first stage.

Wait — 7.2 Hz would cut the breathing signal entirely. Correct: use C2 = 100 µF for f_HP = 1/(2π × 2.2kΩ × 100µF) = **0.72 Hz**, or more practically keep the DC path open and rely on the Stage 1 HP filter at 0.16 Hz. Replace C2 with a direct wire and use only the Stage 1 HP filter. The inverting amplifier then operates with DC feedback:

```
Buffer output ──── [R3: 2.2 kΩ] ──── (−) in (pin 6) ──── [Rf: 100 kΩ] ──── output (pin 7)
                                                                (feedback)
```

**Gain:** Av = −Rf/Rin = −100 kΩ / 2.2 kΩ = **−45.5×** (inverting)

The 20 mV piezo signal becomes ~910 mV — well within the 0–5V ADC range.

**R_LP and C_LP** form the anti-aliasing low-pass filter on the output: f_LP = 1/(2π × 4.7kΩ × 100nF) = **338 Hz**. This is well above the breathing signal (< 2 Hz) but well below the 50 Hz Nyquist limit of the 100 Hz ADC, preventing any high-frequency noise from aliasing into the breathing band.

### DC Bias — Centring at 2.5V

The LM358 output swings around 0V with no bias. The Arduino ADC only accepts 0–5V, so without a DC offset the negative half of the breathing waveform is clipped to GND.

Set the non-inverting input (pin 5) to 2.5V:

```
5V ──── [R_B1: 10 kΩ] ──┬──── (+) in (pin 5)
                         │
                     [R_B2: 10 kΩ]
                         │
                        GND
                         │
                    [C_bypass: 100 nF] ← decouples AC from bias rail
```

With the bias at 2.5V, the output rests at ~2.5V (ADC ≈ 512) and swings up and down with each breath cycle. The full 0–5V ADC range is used.

### Complete A0 Signal Chain Summary

```
Piezo → [1 MΩ + 1 µF HP @ 0.16 Hz] → [LM358A voltage follower]
      → [× −45.5 gain] → [2.5V DC bias] → [LP @ 338 Hz] → A0
```

---

## Channel A1 — Thermistor Voltage Divider

No op-amp needed. The thermistor forms the top leg of a resistive divider:

```
5V ──── [R_ref: 10 kΩ] ──┬──── [R_filter: 1 kΩ] ──── A1
                          │                             │
                     [NTC: 10 kΩ @ 25°C]           [C_f: 100 nF]
                          │                             │
                         GND ─────────────────────────GND
```

**Voltage divider output:** V = 5V × R_NTC / (R_ref + R_NTC)

At 25°C (room temp), R_NTC = R_ref = 10 kΩ → V = **2.5V** (ADC ≈ 512)  
During exhale (~34°C), R_NTC ≈ 7.3 kΩ → V = 5 × 7.3/17.3 = **2.11V** (ADC ≈ 433)  
During inhale (~20°C), R_NTC ≈ 13.4 kΩ → V = 5 × 13.4/23.4 = **2.86V** (ADC ≈ 586)

**ADC swing per breath cycle:** ~153 counts — easily detectable.

**RC low-pass filter** (R_filter and C_f): f_LP = 1/(2π × 1kΩ × 100nF) = **1.59 Hz**. Passes the full breathing rate range (up to 1 Hz) while rejecting electrical noise.

---

## Protection

**Polyfuse:** Place a 200 mA resettable polyfuse in series with the 5V line to the breadboard positive rail. This protects the PC's USB port from a short circuit. Required — demonstrators will verify it is present.

**ADC input protection:** The LM358 output cannot swing beyond its supply rails (0–5V) so the ADC input is inherently protected. No additional clamping diodes are needed, provided the LM358 is powered from the same 5V rail.

---

## Complete Component List for Core Analogue Circuit

| Component | Value | Qty | Source |
|---|---|---|---|
| LM358 dual op-amp DIP-8 | LM358P | 1 | Lab stock |
| Resistor | 1 MΩ | 2 | Lab stock |
| Resistor | 100 kΩ | 1 | Lab stock |
| Resistor | 10 kΩ | 3 | Lab stock |
| Resistor | 4.7 kΩ | 1 | Lab stock |
| Resistor | 2.2 kΩ | 1 | Lab stock |
| Resistor | 1 kΩ | 1 | Lab stock |
| Ceramic capacitor | 100 nF | 4 | Lab stock |
| Electrolytic capacitor | 1 µF | 1 | Lab stock |
| Polyfuse | 200 mA | 1 | Lab stock |

---

## Breadboard Layout Tips

1. Place the LM358 across the central divide — pins 1–4 one side, 5–8 the other
2. Fit the 100 nF decoupling cap immediately adjacent to VCC (pin 8) and GND (pin 4) — not at the far end of the rail
3. Route the piezo wires away from power rails and PWM digital outputs (D9–D11)
4. Keep signal wires short between op-amp output and Arduino ADC — long wires act as antennas and pick up 50 Hz mains
5. Connect all grounds to a single rail before anything else — a floating ground is the most common cause of unexplained noise

---

## Sanity Checks Before First Power-On

| Measurement | Expected value | If wrong |
|---|---|---|
| Voltage at breadboard +ve rail | 5.0V ± 0.1V | Check USB connection, polyfuse |
| LM358 pin 8 (VCC) | 5.0V | Check wiring to rail |
| LM358 pin 4 (GND) | 0V | Check GND connection |
| LM358 pin 5 (non-inv input) | 2.5V | Check bias divider |
| LM358 pin 7 (output, no piezo) | ~2.5V | Op-amp saturated — check feedback |
| Arduino A0 (no movement) | ~512 in Serial Monitor | Bias not reaching ADC |
| Arduino A1 (room temp) | ~540–560 | Check thermistor divider wiring |

---

## Optional Extension — PPG Transimpedance Amplifier (BPW34 + TSAL6400)

If adding the DIY PPG extension (Option A from the components doc), a third analogue channel uses a second LM358 IC as a transimpedance amplifier (TIA).

**Parts required** (see doc 01 for Onecall order codes):
- **Vishay BPW34** silicon PIN photodiode — CPC code SC07697 or Farnell code 1045425
- **Vishay TSAL6400** 940nm IR LED — Farnell code 1652530

```
TSAL6400 anode ──── [R_LED: 150 Ω] ──── D3 (PWM at ~880 Hz for modulation)
TSAL6400 cathode ──── GND

BPW34 anode ──── (−) input of second LM358
BPW34 cathode ──── 5V
[Rf_TIA: 1 MΩ] between (−) input and output
(+) input ──── 2.5V bias (from existing divider)
Output ──── [R_LP: 10 kΩ] ──── A2
                                │
                          [C_LP: 100 nF]
                                │
                               GND
```

**How it works:** The TSAL6400 illuminates the fingertip. The BPW34 detects the reflected IR light — the amount varies with blood volume in the capillaries on each heartbeat, giving the PPG waveform. The transimpedance amplifier converts the BPW34's photocurrent to a voltage: V = I_photo × Rf_TIA. With Rf = 1 MΩ and typical photocurrents of 1–10 µA the output swing is 1–10V — start with Rf = 100 kΩ and increase if the signal is too small.

**TSAL6400 electrical notes:** forward voltage ~1.35V, so the 150 Ω resistor limits current to (5 − 1.35) / 150 ≈ 24 mA — within the safe operating range. Modulating the LED at ~880 Hz and demodulating in firmware or Python (lock-in style) improves rejection of ambient light noise.

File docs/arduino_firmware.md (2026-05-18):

# Arduino Firmware

## Overview

The firmware performs four tasks using a timer-interrupt architecture:

1. **ADC sampling** at exactly 100 Hz on A0 (piezo) and A1 (thermistor) via Timer1 ISR
2. **Rolling FFT** on the piezo channel every 2.56 seconds (256 samples)
3. **Apnea detection** from the thermistor channel (continuous)
4. **Serial communication** — streaming feature packets to Python, parsing command packets back

If the SpO2 extension is fitted, I2C polling of the MAX30100/30102 is added as a fifth task — see the extension section at the end.

---

## Library Installation

Open Arduino IDE → Tools → Manage Libraries:

| Library | Author | Purpose |
|---|---|---|
| `arduinoFFT` | Enrique Blasina | FFT computation |
| `LiquidCrystal_I2C` | Frank de Brabander | LCD over I2C |
| `MAX30100lib` *(extension only)* | OXullo Intersecans | GY-MAX30100 driver |
| `SparkFun MAX3010x` *(extension only)* | SparkFun | MAX30102 driver |

---

## Firmware Architecture

```
setup()
  ├── Serial.begin(115200)
  ├── Wire.begin()                    ← only needed if LCD or SpO2 extension fitted
  ├── lcd.begin() / lcd.backlight()
  ├── Timer1 interrupt configured at 100 Hz
  └── Pin modes: D6 (pacer), D7 (buzzer), D9/D10/D11 (RGB)

loop()
  ├── if (sampleReady)
  │     └── store sample, check apnea on thermistor
  ├── if (fftWindowFull)              ← every 256 samples = 2.56 s
  │     ├── computeFFT()
  │     ├── extractFeatures()
  │     └── sendSerialPacket()
  ├── checkSerialRx()                 ← parse CMD: packets from Python
  └── updateOutputs()                 ← RGB LED, pacer LED, buzzer, LCD

ISR (Timer1 @ 100 Hz)
  ├── analogRead(A0) → piezoBuffer[idx]
  ├── analogRead(A1) → thermoBuffer[idx]
  ├── idx++
  └── set sampleReady flag
```

---

## Timer1 — Exact 100 Hz Sampling

Do not use `delay()` or `millis()` for sampling — they drift and distort FFT frequency accuracy. Use Timer1 in CTC mode to fire an ISR at precisely 100 Hz.

```cpp
#include <avr/interrupt.h>

// Sampling buffers
#define SAMPLES 256
volatile int16_t  piezoBuffer[SAMPLES];   // int16_t saves RAM vs uint16_t
volatile uint16_t thermoBuffer[SAMPLES];
volatile uint8_t  bufferIdx  = 0;
volatile bool     sampleReady = false;
volatile bool     windowFull  = false;

void setupTimer1() {
  cli();
  TCCR1A = 0;
  TCCR1B = 0;
  TCNT1  = 0;
  // 16 MHz / (256 prescaler × 100 Hz) − 1 = 624
  OCR1A  = 624;
  TCCR1B |= (1 << WGM12);   // CTC mode
  TCCR1B |= (1 << CS12);    // prescaler 256
  TIMSK1 |= (1 << OCIE1A);  // enable compare match interrupt
  sei();
}

ISR(TIMER1_COMPA_vect) {
  if (bufferIdx < SAMPLES) {
    // Read both channels back-to-back
    // Each analogRead takes ~104 µs — at 100 Hz ISR period (10 ms) this is fine
    int raw = analogRead(A0);
    piezoBuffer[bufferIdx]  = raw - 512;        // remove DC bias (512 = midpoint)
    thermoBuffer[bufferIdx] = analogRead(A1);
    bufferIdx++;
    sampleReady = true;
    if (bufferIdx == SAMPLES) windowFull = true;
  }
}
```

**Why subtract 512?** Removing the DC component before FFT prevents the zero-frequency bin from dominating the spectrum and masking small breathing-frequency peaks. The bias circuit centres the piezo signal at 512 ADC counts (2.5V), so subtracting 512 gives a zero-mean signal suitable for FFT.

---

## FFT Implementation

```cpp
#include <arduinoFFT.h>

#define SAMPLING_FREQ 100.0f

// Use float (not double) to fit within 2 KB SRAM
float vReal[SAMPLES];
float vImag[SAMPLES];

arduinoFFT FFT = arduinoFFT(vReal, vImag, SAMPLES, SAMPLING_FREQ);

void computeFFT() {
  // Copy piezo buffer into vReal (already DC-removed in ISR)
  for (int i = 0; i < SAMPLES; i++) {
    vReal[i] = (float)piezoBuffer[i];
    vImag[i] = 0.0f;
  }

  FFT.Windowing(FFT_WIN_TYP_HANN, FFT_FORWARD);  // reduce spectral leakage
  FFT.Compute(FFT_FORWARD);
  FFT.ComplexToMagnitude();

  // vReal[0..127] now holds the one-sided magnitude spectrum
  // Frequency resolution: 100 / 256 = 0.39 Hz per bin
  // Breathing band: 0.1–1.0 Hz = bins 0–2 (skip bin 0 = DC residual)
}
```

**Memory note:** `float vReal[256]` + `float vImag[256]` = 2048 bytes. Add `piezoBuffer` (512 bytes) and `thermoBuffer` (512 bytes) = 3072 bytes total — exceeding the ATmega328P's 2048-byte SRAM. Solution: after the ISR fills `piezoBuffer`, copy it to `vReal` inside `computeFFT()`, then reuse `piezoBuffer` for the next window. The arrays are never simultaneously needed at full occupancy. If memory is still tight, reduce to 128 samples (1.28-second window, 0.78 Hz resolution) — still sufficient for breathing analysis.

---

## Feature Extraction

```cpp
struct Features {
  float breathingRate;    // Hz — dominant FFT peak in 0.1–1.5 Hz
  float spectralPower;    // sum of squared magnitudes in breathing band
  float regularity;       // 0–1, sharpness of dominant peak
  float ieRatio;          // inspiratory:expiratory ratio
  uint8_t apneaFlag;      // 1 if no breath for >10 s
  // SpO2 / HR added here if extension fitted
};

Features extractFeatures() {
  Features f;

  // Find dominant bin in breathing band (bins 1–8 = 0.39–3.12 Hz)
  float maxMag    = 0;
  float totalPow  = 0;
  int   peakBin   = 1;

  for (int k = 1; k <= 8; k++) {
    float mag = vReal[k];
    if (mag > maxMag) { maxMag = mag; peakBin = k; }
    totalPow += mag * mag;
  }

  f.breathingRate   = peakBin * (SAMPLING_FREQ / SAMPLES);
  f.spectralPower   = totalPow;
  f.regularityScore = (maxMag * maxMag) / max(totalPow, 1.0f);

  // I:E ratio — fraction of waveform above vs below zero (zero = exhale baseline)
  int above = 0, below = 0;
  for (int i = 0; i < SAMPLES; i++) {
    if (piezoBuffer[i] > 0) above++; else below++;
  }
  f.ieRatio = (float)above / max(below, 1);

  f.apneaFlag = apneaActive ? 1 : 0;

  return f;
}
```

---

## Apnea Detection

```cpp
#define APNEA_THRESHOLD  20    // ADC counts — tune experimentally (start at 20)
#define APNEA_TIMEOUT_S  10    // seconds with no breath before flagging

bool     apneaActive     = false;
uint16_t apneaCounter    = 0;  // counts 100-Hz samples with low thermistor swing

// Called from the ISR or from loop() after each sample
void checkApnea(uint16_t thermoSample) {
  static uint16_t thermoMin = 1023, thermoMax = 0;
  static uint8_t  windowCount = 0;

  if (thermoSample < thermoMin) thermoMin = thermoSample;
  if (thermoSample > thermoMax) thermoMax = thermoSample;

  if (++windowCount >= 200) {  // evaluate every 2 seconds
    uint16_t swing = thermoMax - thermoMin;
    thermoMin = 1023; thermoMax = 0; windowCount = 0;

    if (swing < APNEA_THRESHOLD) {
      apneaCounter += 200;
      if (apneaCounter >= APNEA_TIMEOUT_S * 100 && !apneaActive) {
        apneaActive = true;
        Serial.println(F("DATA:APNEA:1"));
      }
    } else {
      apneaCounter = 0;
      if (apneaActive) {
        apneaActive = false;
        Serial.println(F("DATA:APNEA:0"));
      }
    }
  }
}
```

---

## Serial Communication Protocol

### Outgoing — Feature Packet (Arduino → Python)

Sent every 2.56 seconds after each FFT window:

```
DATA,<breathingRate>,<spectralPower>,<regularity>,<ieRatio>,<apneaFlag>\n
```

Example:
```
DATA,0.47,1842.3,0.73,0.61,0
```

If the SpO2 extension is fitted, two extra fields are appended:
```
DATA,0.47,1842.3,0.73,0.61,0,98.2,72
```

### Incoming — Command Packet (Python → Arduino)

```
CMD:<TYPE>:<VALUE>\n
```

| Command | Example | Arduino action |
|---|---|---|
| `CMD:SEV:<0-3>` | `CMD:SEV:2` | Set RGB LED colour |
| `CMD:BF:<bpm>` | `CMD:BF:6` | Set pacer LED rate (0 = off) |
| `CMD:LCD1:<text>` | `CMD:LCD1:BR 14  SpO2 98` | Write LCD row 0 |
| `CMD:LCD2:<text>` | `CMD:LCD2:NORMAL ` | Write LCD row 1 |
| `CMD:ALERT:<0-1>` | `CMD:ALERT:1` | Buzzer on/off |

```cpp
void checkSerialRx() {
  if (!Serial.available()) return;
  String cmd = Serial.readStringUntil('\n');
  cmd.trim();

  if      (cmd.startsWith(F("CMD:SEV:")))   handleSeverity(cmd.charAt(8) - '0');
  else if (cmd.startsWith(F("CMD:BF:")))    handleBiofeedback(cmd.substring(7).toInt());
  else if (cmd.startsWith(F("CMD:ALERT:"))) handleAlert(cmd.charAt(10) - '0');
  else if (cmd.startsWith(F("CMD:LCD1:")))  { lcd.setCursor(0,0); lcd.print(cmd.substring(9)); }
  else if (cmd.startsWith(F("CMD:LCD2:")))  { lcd.setCursor(0,1); lcd.print(cmd.substring(9)); }
}
```

Use the `F()` macro on all string literals to store them in flash (program memory) rather than SRAM — critical for staying within the 2 KB SRAM limit.

---

## Sending the Feature Packet

```cpp
void sendSerialPacket(Features& f) {
  Serial.print(F("DATA,"));
  Serial.print(f.breathingRate, 3);  Serial.print(',');
  Serial.print(f.spectralPower, 1);  Serial.print(',');
  Serial.print(f.regularity,    3);  Serial.print(',');
  Serial.print(f.ieRatio,       3);  Serial.print(',');
  Serial.print(f.apneaFlag);
  // Append SpO2/HR if extension fitted:
  // Serial.print(','); Serial.print(latestSpO2, 1);
  // Serial.print(','); Serial.print((int)latestHR);
  Serial.println();  // \n terminator
}
```

---

## Main Loop Structure

```cpp
void loop() {
  // 1. Process new samples from ISR
  if (sampleReady) {
    sampleReady = false;
    checkApnea(thermoBuffer[bufferIdx > 0 ? bufferIdx - 1 : 0]);
  }

  // 2. When a full 256-sample window is ready, run FFT
  if (windowFull) {
    windowFull = false;
    bufferIdx  = 0;

    computeFFT();
    Features f = extractFeatures();
    sendSerialPacket(f);

    // Update LCD locally (Python can override with CMD:LCD1/2)
    char line1[17];
    snprintf(line1, 17, "BR%-4.1f         ", f.breathingRate * 60.0f);
    lcd.setCursor(0, 0); lcd.print(line1);
  }

  // 3. Parse any incoming Python commands
  checkSerialRx();

  // 4. Update outputs (non-blocking — see doc 09)
  updateRGBFlash();    // flashing for severity 3
  updatePacer();       // smooth cosine fade on D6
  updateBuzzer();      // beep patterns on D7
}
```

---

## Optional Extension — SpO2 with GY-MAX30100

Add after core system is verified working. The GY-MAX30100 uses I2C and the `MAX30100lib` library.

```cpp
// Add to firmware if GY-MAX30100 extension fitted
#include <Wire.h>
#include "MAX30100_PulseOximeter.h"

PulseOximeter pox;
float latestSpO2 = 0;
float latestHR   = 0;

void initMAX30100() {
  if (!pox.begin()) {
    Serial.println(F("ERR:MAX30100 not found"));
    while(1);
  }
  pox.setIRLedCurrent(MAX30100_LED_CURR_7_6MA);
}

// Call from loop() — the library manages its own timing internally
void pollMAX30100() {
  pox.update();
  latestSpO2 = pox.getSpO2();
  latestHR   = pox.getHeartRate();
}
```

I2C wiring: Arduino A4 (SDA) → MAX30100 SDA, Arduino A5 (SCL) → MAX30100 SCL, Arduino 3.3V → MAX30100 VCC, GND → GND. The GY-MAX30100 module has on-board pull-up resistors.

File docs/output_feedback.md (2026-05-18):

# Output and Feedback Hardware

## Overview

Four physical outputs feed back information to the user without requiring the PC screen — useful during exercise.

| Output | Pin | Function |
|---|---|---|
| RGB LED | D9 (R), D10 (G), D11 (B) | Severity colour indicator |
| Pacer LED (green) | D6 (PWM) | Biofeedback breathing guide |
| Buzzer (active, 5V) | D7 | Apnea / urgent alert |
| LCD 16×2 with I2C | A4/A5 (I2C) | Live BR display and status text |

---

## 1. RGB LED

### Wiring

```
Arduino D9  ──── [220 Ω] ──── RGB LED Red pin
Arduino D10 ──── [150 Ω] ──── RGB LED Green pin
Arduino D11 ──── [150 Ω] ──── RGB LED Blue pin
RGB LED cathode (longest pin) ──── GND
```

**Resistor calculation** (target ~15 mA per channel):
- Red Vf ≈ 2.1V: (5 − 2.1) / 0.015 = 193 Ω → use **220 Ω**
- Green Vf ≈ 3.1V: (5 − 3.1) / 0.015 = 127 Ω → use **150 Ω**
- Blue Vf ≈ 3.1V: (5 − 3.1) / 0.015 = 127 Ω → use **150 Ω**

Using the same resistor for all three would give different perceived brightness; these values normalise the current across channels.

### Firmware

```cpp
const uint8_t SEVERITY_R[] = {0,   255, 255, 255};
const uint8_t SEVERITY_G[] = {200, 165, 0,   0  };
const uint8_t SEVERITY_B[] = {0,   0,   0,   0  };
// Colours: 0=green, 1=amber, 2=red, 3=red (handled by flash)

uint8_t currentSeverity = 0;

void setRGB(uint8_t r, uint8_t g, uint8_t b) {
  analogWrite(9,  r);
  analogWrite(10, g);
  analogWrite(11, b);
}

void handleSeverity(uint8_t level) {
  currentSeverity = level;
  if (level < 3) {
    setRGB(SEVERITY_R[level], SEVERITY_G[level], SEVERITY_B[level]);
  }
  // Level 3 is handled by updateRGBFlash() in loop()
}

// Call from loop() — non-blocking 2 Hz flash for severity 3
uint32_t lastFlash  = 0;
bool     flashState = false;
void updateRGBFlash() {
  if (currentSeverity != 3) return;
  if (millis() - lastFlash > 250) {
    flashState = !flashState;
    setRGB(flashState ? 255 : 0, 0, 0);
    lastFlash = millis();
  }
}
```

---

## 2. Pacer LED — Biofeedback Breathing Guide

A smooth cosine-wave pulse is far more natural to follow than an abrupt on/off flash.

### Wiring

```
Arduino D6 ──── [150 Ω] ──── Green LED anode
Green LED cathode ──── GND
```

D6 supports PWM (`analogWrite()`).

### Firmware — Cosine Fade

```cpp
uint8_t  pacerBPM      = 0;
uint32_t pacerPeriodMs = 0;
uint32_t pacerStartMs  = 0;

void handleBiofeedback(uint8_t bpm) {
  pacerBPM = bpm;
  if (bpm == 0) { analogWrite(6, 0); return; }
  pacerPeriodMs = 60000UL / bpm;
  pacerStartMs  = millis();
}

// Call from loop() every iteration — no delays
void updatePacer() {
  if (pacerBPM == 0) return;
  uint32_t elapsed = (millis() - pacerStartMs) % pacerPeriodMs;
  float    phase   = (float)elapsed / pacerPeriodMs;  // 0.0–1.0
  // Cosine: bright at phase=0 (inhale peak), dim at phase=0.5 (exhale)
  float brightness = 0.5f * (1.0f - cosf(TWO_PI * phase));
  analogWrite(6, (uint8_t)(brightness * 190));  // cap at 190/255
}
```

At 6 br/min (biofeedback for relaxation), `pacerPeriodMs` = 10,000 ms — a full 10-second fade cycle, which the user can clearly see and synchronise to.

---

## 3. Buzzer

### Wiring

Use an **active** (self-drive) piezo buzzer — it only needs a DC HIGH to sound. A passive buzzer requires a PWM tone and is harder to use here.

```
Arduino D7 ──── Buzzer positive terminal
Buzzer negative terminal ──── GND
```

If the buzzer draws > 20 mA (check datasheet), drive it via a 2N2222 NPN transistor:

```
D7 ──── [1 kΩ] ──── transistor base (pin B)
Transistor collector (pin C) ──── buzzer + terminal ──── 5V
Transistor emitter (pin E) ──── GND
```

### Firmware — Alert Patterns

```cpp
enum AlertPattern { ALERT_OFF = 0, ALERT_APNEA = 1, ALERT_URGENT = 2 };
AlertPattern alertMode   = ALERT_OFF;
uint32_t     alertTimer  = 0;
bool         buzzerOn    = false;
uint8_t      beepCount   = 0;

void handleAlert(uint8_t pattern) {
  alertMode = (AlertPattern)pattern;
  if (pattern == 0) { digitalWrite(7, LOW); buzzerOn = false; }
}

void updateBuzzer() {
  uint32_t now = millis();
  switch (alertMode) {
    case ALERT_OFF: break;

    case ALERT_APNEA:
      // 3 short beeps (200 ms on, 300 ms off) then 2.5 s silence, repeat
      if (beepCount < 3) {
        if (!buzzerOn && now - alertTimer > 300) {
          digitalWrite(7, HIGH); buzzerOn = true; alertTimer = now;
        } else if (buzzerOn && now - alertTimer > 200) {
          digitalWrite(7, LOW);  buzzerOn = false; alertTimer = now; beepCount++;
        }
      } else if (now - alertTimer > 2500) {
        beepCount = 0; alertTimer = now;
      }
      break;

    case ALERT_URGENT:
      // Fast continuous beep at 5 Hz
      if (now - alertTimer > 100) {
        buzzerOn = !buzzerOn;
        digitalWrite(7, buzzerOn ? HIGH : LOW);
        alertTimer = now;
      }
      break;
  }
}
```

---

## 4. LCD 16×2 with I2C Backpack

### Wiring

```
Arduino 5V  ──── LCD VCC
Arduino GND ──── LCD GND
Arduino A4  ──── LCD SDA   (shared I2C bus)
Arduino A5  ──── LCD SCL   (shared I2C bus)
```

The I2C backpack's address is 0x27 (most common) or 0x3F. Run the I2C scanner sketch to confirm.

### Firmware

```cpp
#include <LiquidCrystal_I2C.h>
LiquidCrystal_I2C lcd(0x27, 16, 2);

void initLCD() {
  lcd.init();
  lcd.backlight();
  lcd.setCursor(0,0); lcd.print(F("Resp Monitor    "));
  lcd.setCursor(0,1); lcd.print(F("Initialising... "));
}

// Update after each FFT window with live values
// Python can override via CMD:LCD1: and CMD:LCD2:
void updateLCDLocal(float brBPM, bool apnea) {
  char row0[17], row1[17];
  snprintf(row0, 17, "BR %-4.1f br/min  ", brBPM);
  snprintf(row1, 17, apnea ? "!!! APNEA !!!   " : "                ");
  lcd.setCursor(0,0); lcd.print(row0);
  lcd.setCursor(0,1); lcd.print(row1);
}
```

### I2C Address Scanner

If the LCD does not appear, run this once to find its address:

```cpp
#include <Wire.h>
void setup() {
  Wire.begin(); Serial.begin(115200);
  Serial.println(F("Scanning I2C..."));
  for (byte a = 8; a < 127; a++) {
    Wire.beginTransmission(a);
    if (Wire.endTransmission() == 0)
      Serial.println(a, HEX);
  }
}
void loop() {}
```

---

## Power Budget

| Device | Current |
|---|---|
| RGB LED (all max) | 3 × 15 mA = 45 mA |
| Pacer LED | 15 mA |
| Buzzer | ≤ 20 mA |
| LCD backlight | ~20 mA |
| Op-amp (LM358) | < 5 mA |
| Thermistor divider | < 1 mA |
| **Total** | **~106 mA** |

Well within the USB 2.0 500 mA limit. Use a **200 mA polyfuse** on the 5V breadboard rail (a 100 mA fuse would blow on peak current).

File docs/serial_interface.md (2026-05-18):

# Python Serial Interface

## Overview

Python communicates with the Arduino over USB serial at 115200 baud using `pyserial`. A dedicated background thread reads incoming data continuously so the main GUI thread never blocks. A separate method sends command strings to the Arduino.

---

## Installation

```bash
pip install pyserial
```

**Finding the Arduino port:**
- Windows: Device Manager → Ports (COM & LPT) → Arduino Uno (COMx)
- Linux: `ls /dev/ttyACM*` or `ls /dev/ttyUSB*`
- Mac: `ls /dev/cu.usbmodem*`

---

## Message Protocol

### Incoming — Arduino → Python

| Prefix | Format | Example |
|---|---|---|
| `DATA` | `DATA,<br_hz>,<power>,<reg>,<ie>,<apnea>` | `DATA,0.47,1842.3,0.73,0.61,0` |
| `DATA` (with extension) | `DATA,...,<spo2>,<hr>` | `DATA,0.47,1842.3,0.73,0.61,0,98.2,72` |
| `DATA:APNEA` | `DATA:APNEA:<0 or 1>` | `DATA:APNEA:1` |
| `ERR` | `ERR:<message>` | `ERR:MAX30100 not found` |

All messages are ASCII, newline-terminated (`\n`).

### Outgoing — Python → Arduino

| Command | Format | Example |
|---|---|---|
| Severity | `CMD:SEV:<0-3>` | `CMD:SEV:2` |
| Biofeedback rate | `CMD:BF:<bpm>` | `CMD:BF:6` |
| LCD row 1 | `CMD:LCD1:<up to 16 chars>` | `CMD:LCD1:BR 14.2 NORMAL` |
| LCD row 2 | `CMD:LCD2:<up to 16 chars>` | `CMD:LCD2:SpO2 98  HR 72` |
| Alert | `CMD:ALERT:<0 or 1>` | `CMD:ALERT:1` |

---

## SerialHandler Class

```python
# python/serial_handler.py

import serial
import serial.tools.list_ports
import threading
import queue
import time

class SerialHandler:
    """
    Bidirectional serial link to Arduino.
    Background thread reads lines and places them in a thread-safe queue.
    Main thread calls get_message() to retrieve them non-blocking.
    """

    def __init__(self, port: str, baud: int = 115200):
        self.port     = port
        self.baud     = baud
        self.ser      = None
        self._queue   = queue.Queue(maxsize=200)
        self._running = False
        self._thread  = None

    def connect(self) -> bool:
        try:
            self.ser = serial.Serial(
                port     = self.port,
                baudrate = self.baud,
                timeout  = 1.0,
            )
            time.sleep(2.0)              # wait for Arduino reset after DTR assertion
            self.ser.reset_input_buffer()
            self._running = True
            self._thread  = threading.Thread(target=self._read_loop, daemon=True)
            self._thread.start()
            return True
        except serial.SerialException as e:
            print(f"[Serial] Connection failed on {self.port}: {e}")
            return False

    def _read_loop(self):
        while self._running:
            try:
                if self.ser.in_waiting:
                    raw  = self.ser.readline()
                    line = raw.decode('utf-8', errors='ignore').strip()
                    if line and not self._queue.full():
                        self._queue.put(line)
            except serial.SerialException:
                break
            except Exception as e:
                print(f"[Serial] Read error: {e}")

    def get_message(self, timeout: float = 0.0) -> str | None:
        """Return next message or None if queue is empty."""
        try:
            return self._queue.get(block=timeout > 0, timeout=timeout)
        except queue.Empty:
            return None

    def send(self, command: str):
        """Send a command string to the Arduino (newline appended)."""
        if self.ser and self.ser.is_open:
            try:
                self.ser.write((command + '\n').encode('utf-8'))
            except serial.SerialException as e:
                print(f"[Serial] Write error: {e}")

    def disconnect(self):
        self._running = False
        if self._thread:
            self._thread.join(timeout=2.0)
        if self.ser and self.ser.is_open:
            self.ser.close()

def find_arduino_port() -> str | None:
    """Scan all serial ports and return the first that looks like an Arduino."""
    for port in serial.tools.list_ports.comports():
        desc = (port.description or "").lower()
        dev  = (port.device    or "").lower()
        if any(kw in desc for kw in ("arduino", "ch340", "ft232", "atmega")):
            return port.device
        if "ttyacm" in dev or "ttyusb" in dev:
            return port.device
    return None
```

---

## Data Parser

```python
# python/feature_extractor.py

from dataclasses import dataclass, field
from typing import Optional
import time

@dataclass
class RespiratoryFeatures:
    breathing_rate:  float          # Hz
    spectral_power:  float          # arbitrary
    regularity:      float          # 0–1
    ie_ratio:        float          # dimensionless
    apnea_flag:      int            # 0 or 1
    timestamp:       float          # time.time()
    # Optional extension fields — None if not fitted
    spo2:            Optional[float] = None   # %
    heart_rate:      Optional[float] = None   # bpm

    @property
    def breathing_rate_bpm(self) -> float:
        return self.breathing_rate * 60.0

def parse_data_packet(line: str) -> Optional[RespiratoryFeatures]:
    """Parse a DATA,... line. Returns None on error or non-DATA lines."""
    if not line.startswith("DATA,"):
        return None
    try:
        parts = line.split(',')
        base = RespiratoryFeatures(
            breathing_rate = float(parts[1]),
            spectral_power = float(parts[2]),
            regularity     = float(parts[3]),
            ie_ratio       = float(parts[4]),
            apnea_flag     = int(parts[5]),
            timestamp      = time.time(),
        )
        # Extension fields if present
        if len(parts) >= 8:
            base.spo2       = float(parts[6])
            base.heart_rate = float(parts[7])
        return base
    except (ValueError, IndexError):
        return None
```

---

## Auto Port Detection in main.py

```python
# python/main.py  (simplified)

from serial_handler import SerialHandler, find_arduino_port
import sys

def main():
    port = find_arduino_port()
    if port is None:
        print("Arduino not found. Check USB cable and driver.")
        sys.exit(1)

    print(f"Found Arduino on {port}")
    handler = SerialHandler(port)
    if not handler.connect():
        sys.exit(1)

    # ... initialise classifier, LLM, GUI
    # handler.disconnect() called on exit

if __name__ == "__main__":
    main()
```

---

## Debugging Tips

| Symptom | Cause | Fix |
|---|---|---|
| Port not found by auto-detect | Driver not installed | Install CH340 or FTDI driver for your OS |
| Data arrives garbled | Baud rate mismatch | Confirm `Serial.begin(115200)` in firmware |
| No data at all | Another program has the port open | Close Arduino Serial Monitor before running Python |
| First few packets are garbage | Arduino still resetting | The `time.sleep(2.0)` handles this; increase to 3.0 if needed |
| Queue fills up (dropped packets) | GUI processing too slow | Increase `maxsize`, or reduce FFT packet rate |
| `CMD:` commands appear ignored | Arduino not in `checkSerialRx()` path | Verify `checkSerialRx()` is called every `loop()` iteration |

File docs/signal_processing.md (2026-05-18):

# 04 — Signal Processing

## Why FFT for Respiratory Analysis

A breathing waveform is quasi-periodic — it repeats at the breathing rate with some variation in period and amplitude. The FFT decomposes this into constituent frequencies and reveals:

- **Where energy concentrates** — the dominant frequency peak is the breathing rate
- **How regular breathing is** — a narrow, sharp peak means consistent breathing; a broad diffuse spectrum means irregular or variable pattern
- **Whether multiple components are present** — harmonics, motion artefacts, or the superimposed tremor that distinguishes certain breathing disorders

This information is inaccessible from the raw time-domain waveform without considerably more complex processing.

---

## Sampling Theory

**Sampling rate:** 100 Hz  
**Nyquist limit:** 50 Hz  
**Useful respiratory band:** 0.1–2.0 Hz

The 100 Hz rate is far above the Nyquist minimum for breathing (which would only require 4 Hz). This oversampling means the anti-aliasing filter can be gentle (338 Hz corner), and the waveform shape — particularly the inspiratory-to-expiratory ratio — is captured with high temporal resolution.

---

## FFT Window and Frequency Resolution

With N = 256 samples at fs = 100 Hz:

| Parameter | Value |
|---|---|
| Window duration | 256 / 100 = **2.56 seconds** |
| Frequency resolution | 100 / 256 = **0.39 Hz per bin** |
| Maximum frequency | 100 / 2 = **50 Hz** |
| Useful one-sided bins | 128 (bins 0–127) |

**Bin-to-breathing-rate mapping:**

| Bin | Frequency (Hz) | Breaths per minute |
|---|---|---|
| 0 | 0 Hz | DC — always removed |
| 1 | 0.39 Hz | 23 br/min |
| 2 | 0.78 Hz | 47 br/min |
| 3 | 1.17 Hz | 70 br/min |

Normal resting breathing (12–20 br/min = 0.20–0.33 Hz) falls between bins 0 and 1. The 0.39 Hz resolution cannot distinguish 12 from 20 br/min from the bin index alone. Use quadratic interpolation in Python for sub-bin precision:

```python
def refine_peak(spectrum, peak_bin, freq_resolution):
    if peak_bin <= 0 or peak_bin >= len(spectrum) - 1:
        return peak_bin * freq_resolution
    y0 = spectrum[peak_bin - 1]
    y1 = spectrum[peak_bin]
    y2 = spectrum[peak_bin + 1]
    delta = 0.5 * (y0 - y2) / (y0 - 2*y1 + y2)
    return (peak_bin + delta) * freq_resolution
```

Alternatively, send all 16 low-frequency bins from the Arduino to Python for full-precision interpolation there.

---

## Hann Window

Without windowing, the FFT assumes the signal repeats periodically. A 2.56-second window captures a non-integer number of breath cycles, causing **spectral leakage** — energy from the breathing peak smears into adjacent bins, making regular breathing look irregular.

The Hann window multiplies the time-domain data by a cosine-shaped taper, reducing leakage dramatically. Tradeoff: slight widening of the main lobe (~1.5× wider), which is acceptable for breathing analysis. Applied automatically by the `arduinoFFT` library.

---

## Feature Extraction

### 1. Breathing Rate

Dominant frequency in the band 0.15–1.5 Hz (bins 1–4 at 0.39 Hz resolution). Take the bin with maximum magnitude and apply quadratic interpolation.

| Rate | Class |
|---|---|
| < 0.20 Hz (< 12 br/min) | Bradypnea |
| 0.20–0.33 Hz (12–20 br/min) | Normal eupnea |
| 0.33–0.50 Hz (20–30 br/min) | Mild tachypnea |
| > 0.50 Hz (> 30 br/min) | Tachypnea |

### 2. Spectral Power

Sum of squared FFT magnitudes in the breathing band. Proportional to the square of tidal volume (breath depth). Increases with exercise intensity as depth increases alongside rate.

```
P = Σ |X[k]|² for k in bins 1..8
```

### 3. Regularity Score

Ratio of peak-bin power to total band power:

```
R = |X[peak_bin]|² / P
```

Range 0–1: 0 = completely irregular, 1 = perfectly sinusoidal.

| Value | Interpretation |
|---|---|
| 0.7–0.9 | Regular breathing (rest or steady exercise) |
| 0.5–0.7 | Mildly irregular (variable depth or rate) |
| 0.3–0.5 | Irregular (Cheyne-Stokes, hyperventilation) |
| < 0.3 | Very irregular or apnea |

### 4. Inspiratory-to-Expiratory (I:E) Ratio

In the time domain, inhale causes positive piezo deflection (chest expansion above the DC bias) and exhale causes negative deflection. The fraction of samples above zero reflects the relative duration of each phase.

```python
def ie_ratio(waveform):
    above = np.sum(np.array(waveform) > 0)
    below = np.sum(np.array(waveform) < 0)
    return above / max(below, 1)
```

| I:E | Typical context |
|---|---|
| ~0.5 | Normal rest (inhale ~33% of cycle) |
| ~0.7 | Light exercise |
| ~1.0 | Heavy exercise (equal inhale/exhale) |
| > 1.5 | Obstructive pattern (prolonged inhale) |

---

## Two-Channel Complementarity

The piezo and thermistor provide independent but complementary information:

| Feature | Piezo | Thermistor |
|---|---|---|
| Breathing rate | ✓ Good | ✓ Good |
| Tidal volume | ✓ (amplitude proxy) | ✗ |
| I:E ratio | ✓ (waveform shape) | ✗ |
| Regularity | ✓ (FFT shape) | Partial |
| Apnea detection | Partial (chest may still move in obstructive apnea) | ✓ Best (airflow stops) |
| Motion artefact resistance | Lower | Higher |

Using both channels together is more reliable than either alone. In particular, obstructive sleep apnea can show continued chest movement (the person tries to breathe) while airflow stops entirely — this is only detectable by comparing the two channels, which is exactly what the firmware's apnea detector does.

---

## Exercise-Specific Signal Characteristics

| Parameter | Rest | Light | Moderate | High |
|---|---|---|---|---|
| Breathing rate | 12–16 br/min | 16–24 br/min | 24–36 br/min | 36–50 br/min |
| Spectral power | Low | Medium | High | Very high |
| Tidal volume | Low | Increasing | High | High |
| I:E ratio | ~0.5 | ~0.6 | ~0.7 | ~0.9 |
| Regularity | High | High | Moderate | Variable |

**Recovery rate** is one of the most clinically meaningful metrics. After stopping exercise, breathing rate should return within 2 br/min of baseline within:

- < 2 minutes: excellent cardiovascular fitness
- 2–5 minutes: average fitness
- > 5 minutes: below average

Python tracks this by monitoring the breathing rate time series after the ML classifier transitions from an exercise class back toward normal.

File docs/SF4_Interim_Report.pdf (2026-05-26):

## SF4: Data Logger – Interim Design Report

Smart Guitar Effects Processor & Data Logger

Name(s): Gijeong Lee, Jaehyung Choi CRSid(s): gl534, jc2409
Group No.: 3
Date: May 26, 2026

### 1 Introduction & Application Specification

The primary objective of this project is to develop an advanced embedded system utilising the Arduino Uno hardware platform (powered by the ATmega328P MCU) configured as an interactive Smart Guitar Effects Processor and Data Logger. This directly addresses the requirement to specify an application demonstrating two-way communication between the MCU and PC.

### 2 Conceptual System Design & Communications

The system architecture is strictly partitioned into three specialised operational environments: Analogue Circuitry, Arduino UNO R3 Firmware, and Host PC Software.
Below is the block diagram for communications, illustrating the full signal path and JSON payload exchange over the 115200 Bd USB Serial Bridge.

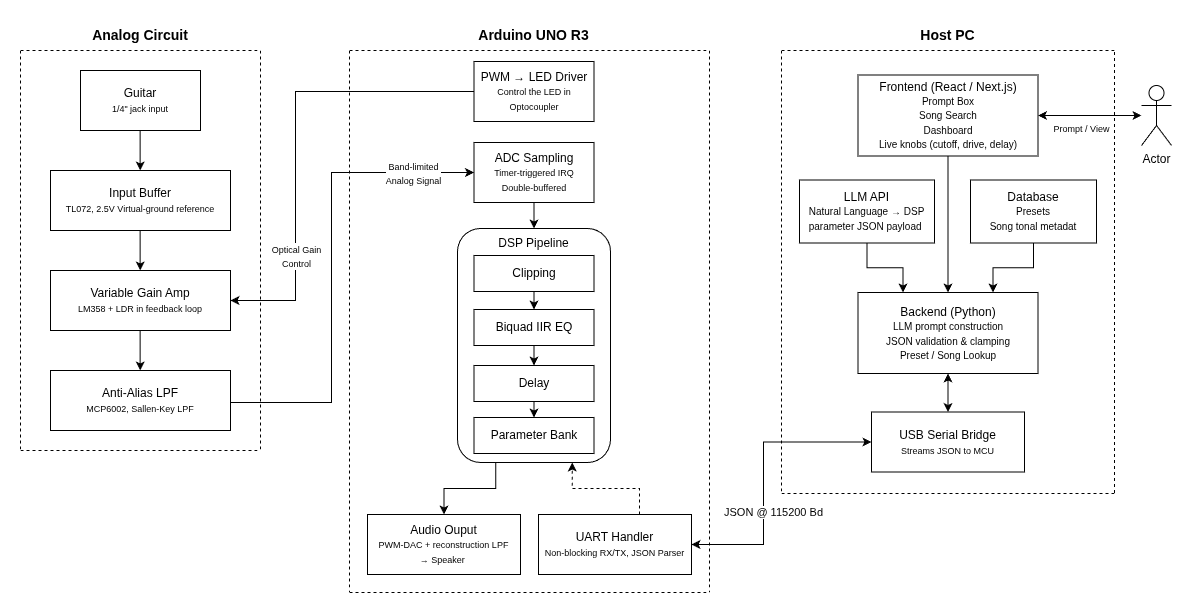
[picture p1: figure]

Figure 1: Systems and Communications Block Diagram.

### 3 Detailed Hardware Design

The custom analogue conditioning hardware consists of three distinct processing stages engineered to precisely scale and map a guitar’s low-voltage signal into the Arduino’s 0 − 5 V single-ended ADC input window. The complete analogue circuit design is provided below.

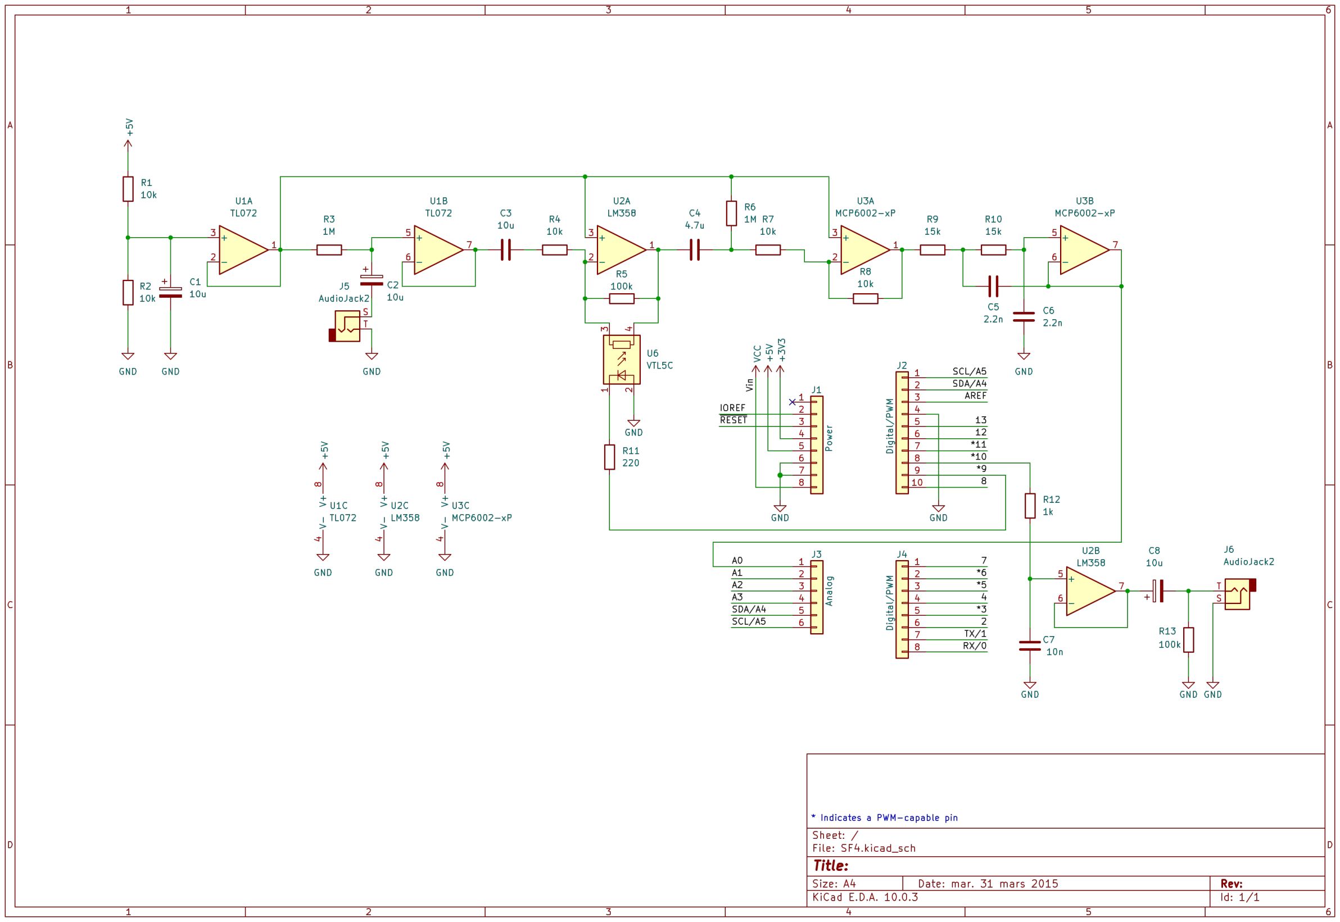
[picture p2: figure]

Figure 2: Analogue Circuit Design Schematic.

1

### 4 Firmware & Software Implementation Plan

The firmware architecture circumvents standard blocking Arduino function libraries to sustain low-latency real-time audio operations, utilising Timer1 interrupts for 20 kHz sampling. The Host PC software utilises a React/Next.js frontend and Python backend to handle LLM-driven JSON parameter generation.

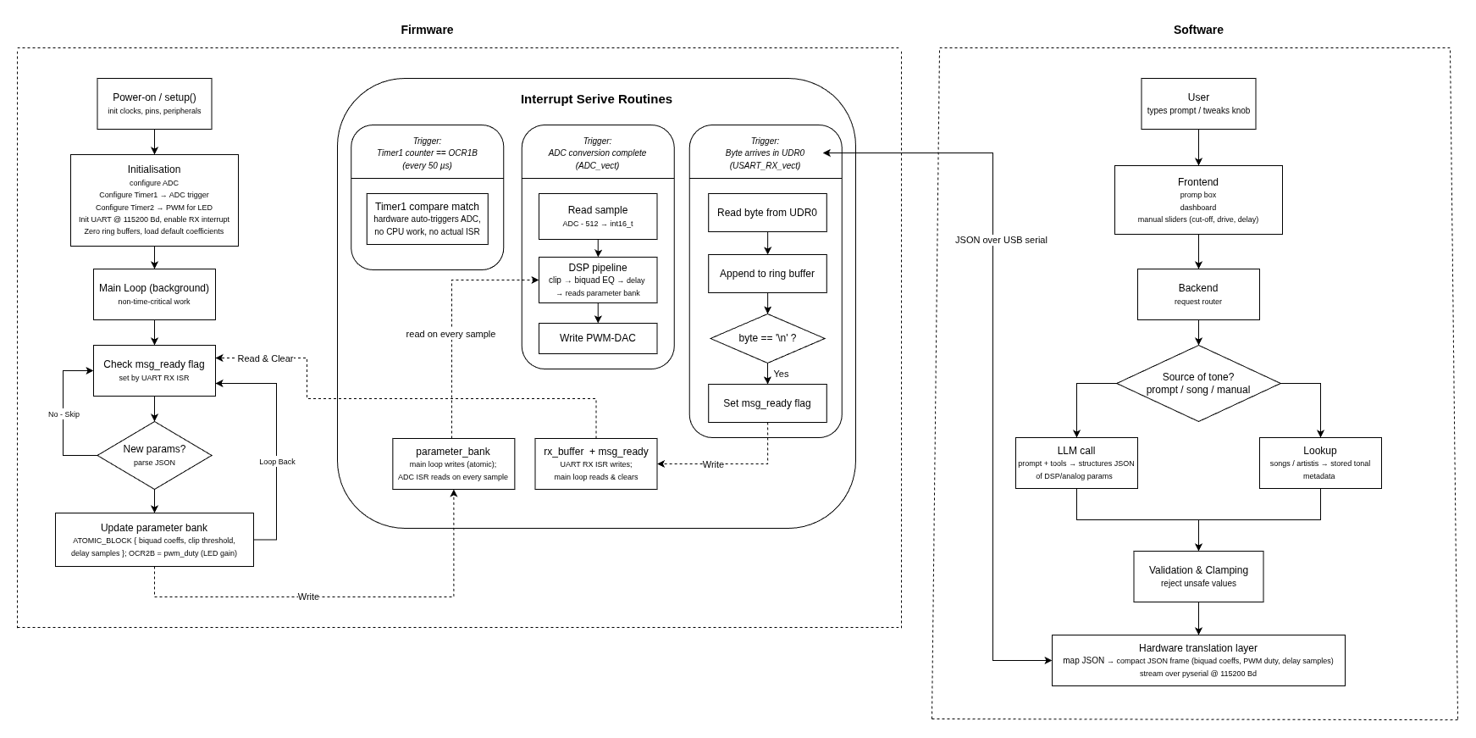
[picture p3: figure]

Figure 3: Firmware and Software Flow Diagram.

### 5 Component Requirements & Parts List

To assemble the target custom prototype circuit board, components have been selected within the strict £15.00 project budget limit.

Table 1: Parts List for Purchasing (BOM)

Order Code | Brief Component Description | Qty | Unit Price (£) Total (£)
SC17220 | JFET-Input Dual Op-Amp (TL072CP) | 2 | 1.000 | 2.000
SC17198 | Dual Low-Power Op-Amps (LM358AP) | 5† | 0.370 | 1.850
1292245 | Rail-to-Rail Dual Op-Amp (MCP6002-I/P) | 2 | 0.346 | 0.692
3692218 | Optocoupler / Vactrol (NSL-32SR3) | 1 | 3.290 | 3.290
CN23320 | 6.35mm (1/4”) PCB Mono Jack Socket | 1 | 0.930 | 0.930
CN22697 | 3.5mm Stereo Panel Jack Socket | 1 | 0.330 | 0.330
Total Custom Expenditure (Budget: £15.00) | £9.092

† Component requires a minimum order quantity of 5 items.

### 6 Work Allocation

To optimise execution efficiency across the remaining two-week timeline, work tasks are divided as follows:

- Gijeong Lee (CRSid: gl534): Primary ownership of hardware layout; responsible for breadboarding the analogue front-end, testing the Sallen-Key low-pass active filter blocks, and calibrating physical optocoupler compression metrics.
- Jaehyung Choi (CRSid: jc2409): Primary ownership of software and firmware; responsible for creating register-direct Timer1 interrupts, coding the real-time biquad filtering framework, configuring non-blocking asynchronous UART handlers, and building the HOST PC python/Next.js interface.

2

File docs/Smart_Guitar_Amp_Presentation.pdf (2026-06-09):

# Smart Guitar Amp

# Analog signal chain + Arduino DSP firmware + voice / LLM tone control

## Presented by · Jaehyung Choi / Gijeong Lee

# Agenda

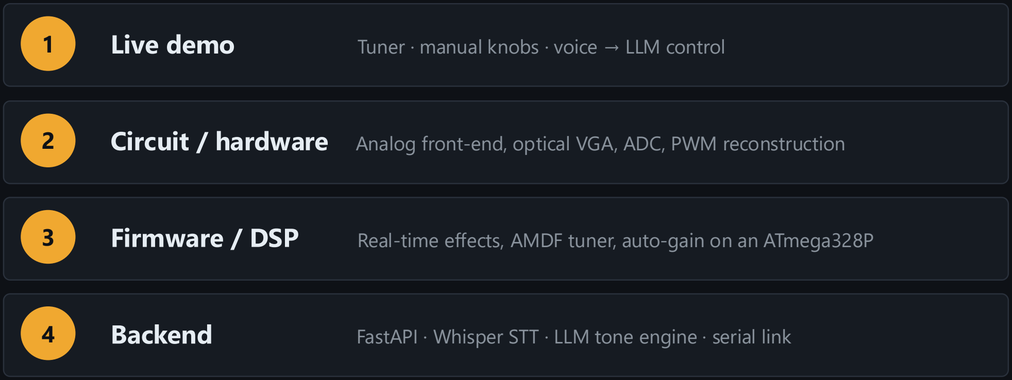
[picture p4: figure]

1 | Live demo | Tuner · manual knobs · voice → LLM control

## 2 Circuit / hardware Analog front-end, optical VGA, ADC, PWM reconstruction

3 | Firmware / DSP | Real-time effects, AMDF tuner, auto-gain on an ATmega328P
4 | Backend | FastAPI · Whisper STT · LLM tone engine · serial link

## S W I T C H T O T H E A P P

# LIVE DEMO

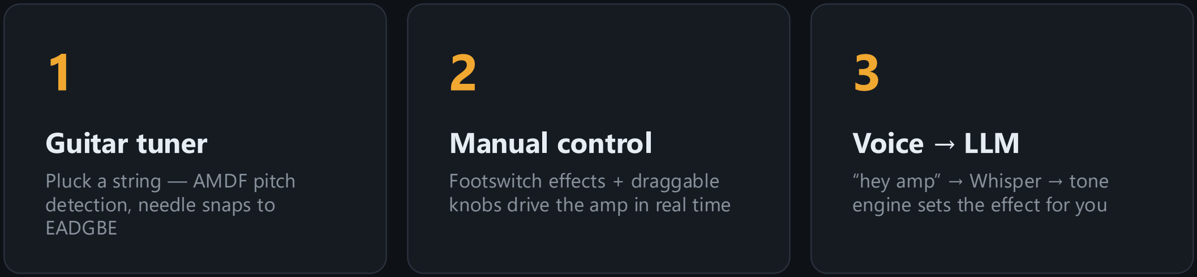
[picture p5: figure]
Guitar tuner; Pluck a string — AMDF pitch detection, needle snaps to EADGBE; Manual control; Footswitch effects + draggable knobs drive the amp in real time; Voice → LLM; “hey amp” → Whisper → tone engine sets the effect for you

# System Overview — three layers, one signal path

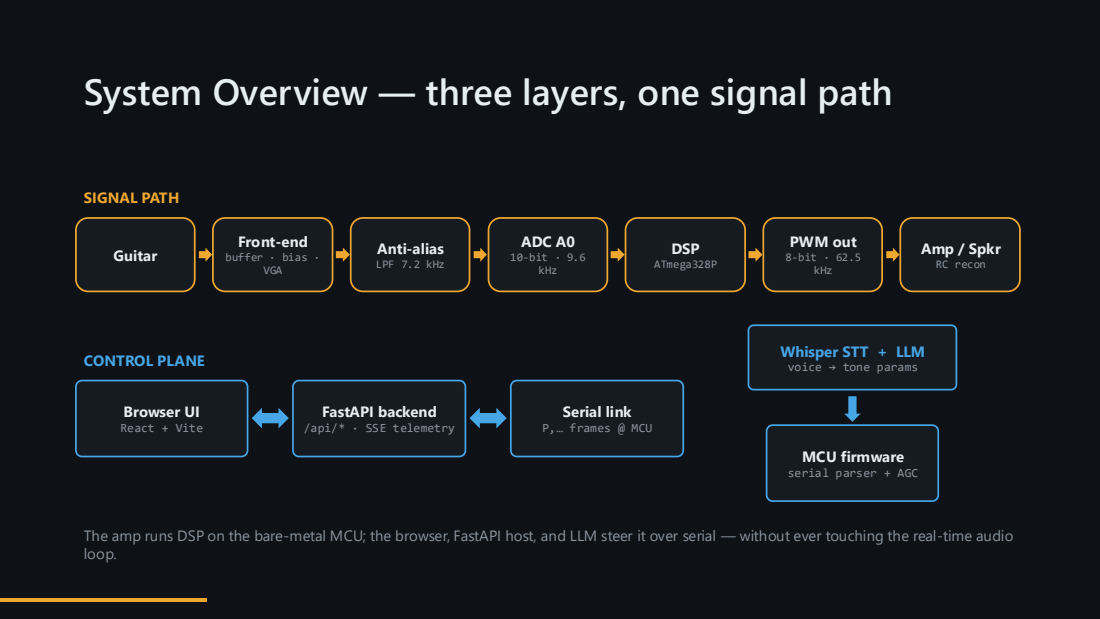
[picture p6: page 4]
CONTROL PLANE; Browser UI React + Vite; Serial link P,… frames @ MCU; Guitar; Front-end buffer · bias · VGA; Anti-alias LPF 7.2 kHz; ADC A0 10-bit · 9.6 kHz; DSP ATmega328P; PWM out 8-bit · 62.5 kHz; Amp / Spkr RC recon; SIGNAL PATH

Whisper STT + LLM
voice → tone params

FastAPI backend
/api/* · SSE telemetry

MCU firmware
serial parser + AGC

The amp runs DSP on the bare-metal MCU; the browser, FastAPI host, and LLM steer it over serial — without ever touching the real-time audio
loop.

## SECTION 01

# Circuit / Hardware

# Analog signal conditioning — guitar level in, line level out

# Analog signal chain

### Input buffer

Z-in · 2.5V bias

### Optocoupler VGA

gain · pin 9

### Anti-alias LPF

fc 7.2 kHz

### ADC A0

10-bit · 9.6 kHz

### DSP core

ATmega328P

### PWM out

pin 10 · 62.5 kHz

### RC reconstruct

2-stage · −44 dB

### Output coupling

HPF 0.16 Hz

## INPUT → signal flows left to right → OUTPUT

Single 5V rail · bipolar audio rides a 2.5V virtual ground · all gain set optically (no digital noise into the analog path)

# Input stage — bias & AC coupling

## COMPONENTS

## R1 — 10 kΩ

Series input resistor → high-Z input (~MΩ with op-amp), won't load the pickup

## C1 — 10 µF

AC-coupling cap: blocks the guitar's DC, passes only the audio swing

## 2.5 V virtual ground

Mid-rail bias so a single 5 V supply carries a bipolar (±) audio signal

## WHY 2.5 V BIAS?

The Uno runs on one 5 V rail — it can't represent a negative voltage. Centring the signal at 2.5 V lets the waveform swing up and down around mid-rail, so the ADC sees the full ± audio without a split supply.

## OP-AMP CHOICE

LM358 / MCP6002 — rail-to-rail, swings near 0–5 V on a single supply

# Optocoupler VGA — silent gain

## SIGNAL FLOW

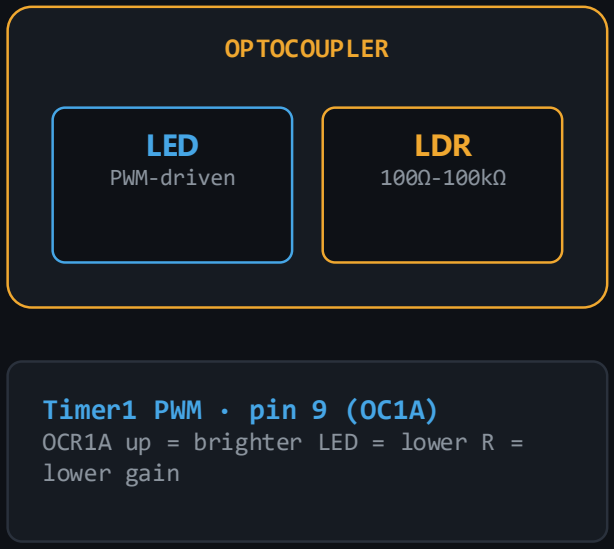
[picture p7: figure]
OPTOCOUPLER; LED PWM-driven; LDR 100Ω-100kΩ; Timer1 PWM · pin 9 (OC1A) OCR1A up = brighter LED = lower R = lower gain

### Audio in

from buffer
→

## WHY OPTICAL?

### DC-free gain control

Light couples LED to LDR — no electrical path into the audio, so no DC offset injected.

### Silent & click-free

Resistance glides smoothly — no zipper noise like a digital pot or switched gain.

### No switching noise

PWM stays on the LED side; the analog path never sees the digital edges.

# Anti-alias filter & ADC

## FILTER & SAMPLING

## Sallen-Key LPF

R7 = R8 = 10 kΩ · C5 = C6 = 2.2 nF fc ≈ 7.2 kHz (2nd-order)

## ADC input

A0 · 10-bit · free-running prescaler 128 → 9615 Hz

## Nyquist

Fs / 2 = 4.8 kHz
covers full guitar range

Guitar band sits safely below both the filter corner and Nyquist.

## WHY PRESCALER 128, NOT 64?

### Slower clock = longer echoes

64 would sample at ~19 kHz. Halving to 128 (9.6 kHz) doubles the time the 512-byte buffer spans — max delay/reverb roughly doubles.

### Nyquist still covers guitar

4.8 kHz Nyquist is well above the guitar's top harmonics, so nothing audible is lost by going slower.

### Filter guards the band

The 7.2 kHz Sallen-Key rolls off anything that could alias back into the audio.

# PWM output & reconstruction

## RECONSTRUCTION CHAIN · pin 10 / OC1B

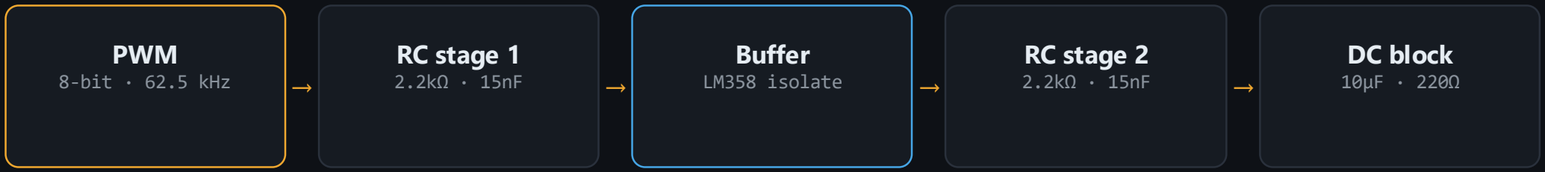
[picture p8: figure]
PWM; 8-bit · 62.5 kHz; RC stage 1; Buffer; LM358 isolate; RC stage 2; DC block 10µF · 220Ω

each RC ≈ 4.8 kHz/stage → ~−44 dB at carrier, flat guitar passband | · | HPF ≈ 0.16 Hz

### Timer1 — Mode 5, 8-bit Fast PWM

TCCR1A = (1<<COM1A1)|(1<<COM1B1)|(1<<WGM10); TCCR1B = (1<<WGM12)|(1<<CS10); // /1 → 62.5 kHz
OCR1B = 128; | // mid-rail idle

// in the ADC ISR:
OCR1B = processEffect(ADC) >> 2;

## WHY 62.5 kHz?

Not 15.6 kHz
Carrier far above audio means a gentle passive RC can reject it AND pass the full guitar band. Trade: 10-bit → 8-bit
256 levels (~48 dB) is plenty for a guitar effect.

## SECTION 02

# Firmware / DSP

# Real-time fixed-point effects on an ATmega328P

# Real-time architecture — the ISR

## ADC ISR · fires ~9 615×/sec · ~52 µs budget per sample

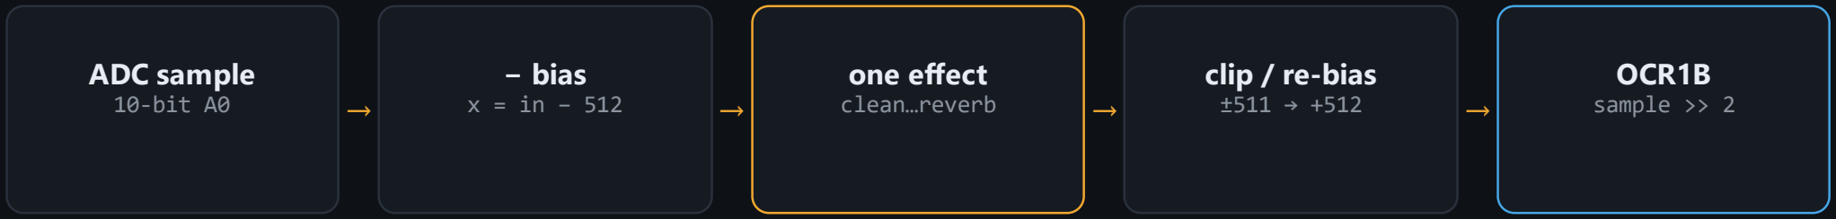
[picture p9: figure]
ADC sample; 10-bit A0; − bias; one effect; clean…reverb; clip / re-bias; OCR1B sample >> 2

struct Params — written by loop(), read by ISR

uint8_t effect; | // FX_CLEAN … FX_TUNER
int16_t thresh; | // overdrive drive 1..511
uint16_t delayLen; // tap distance | 1..512
uint8_t feedback; // regen Q8 | 0..255
uint8_t mix; | // wet level Q8 | 0..255
uint8_t depth; | // chorus depth | 1..48
uint8_t rate; | // chorus LFO rate 1..20

## DESIGN RULES

Fixed-point only
No float in the ISR — every effect is integer shifts & adds. 512-byte ring buffer
audioBuf holds ~53 ms of history for delay / reverb / chorus. Atomic updates
Params swapped in one cli/sei block — ISR never reads a half-write.

# Overdrive — pre-amplify, then hard-clip

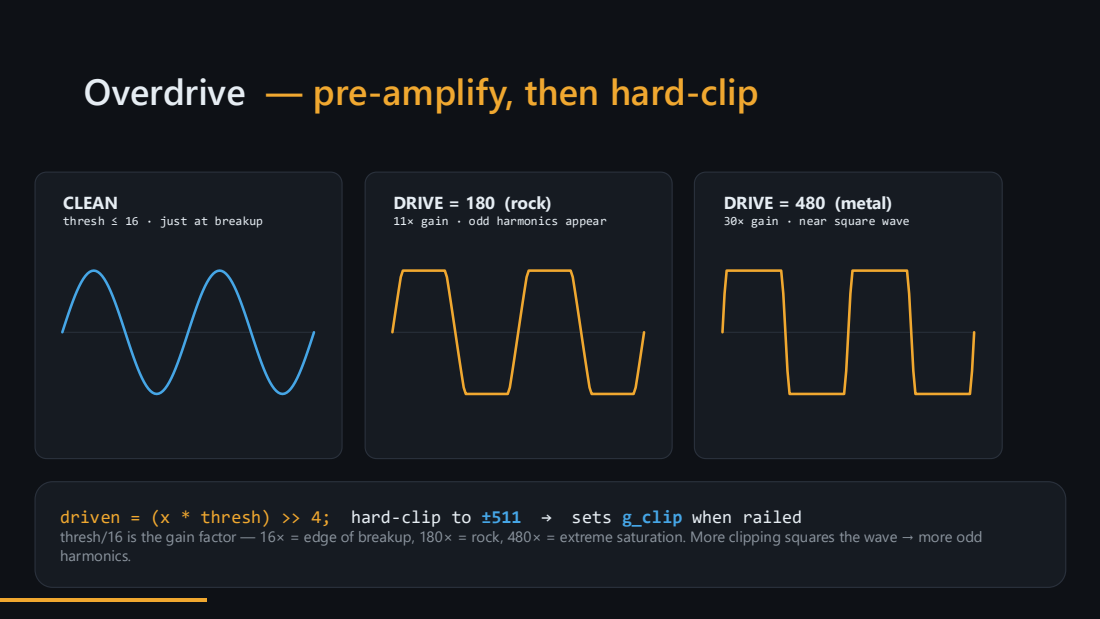
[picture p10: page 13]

CLEAN
thresh ≤ 16 · just at breakup

DRIVE = 180 (rock)
11× gain · odd harmonics appear

DRIVE = 480 (metal)
30× gain · near square wave

driven = (x * thresh) >> 4; hard-clip to ±511 → sets g_clip when railed
thresh/16 is the gain factor — 16× = edge of breakup, 180× = rock, 480× = extreme saturation. More clipping squares the wave → more odd
harmonics.

# Delay — ring-buffer echo

## 512-SAMPLE RING BUFFER

tap | W
| write →

delayLen back

DECAYING TAIL (feedback regenerates)

### t = delayLen / 9615 Hz ≤ 53 ms slapback

### Per-sample, in the ISR

echo = buf[(w − delayLen) & MASK]
out | = x + (echo·mix | >> 8) | // wet
store = x + (echo·feedback >> 8) // tail buf[w] = store >> 2; w = (w+1) & MASK

## HOW IT WORKS

One read tap, delayLen samples behind the write head, gives the echo.

Feeding the echo back into the store builds a recursive, decaying repeat — slapback to long trails.

# Chorus — modulated tap

## TRIANGLE LFO

period 65536 · phase += rate (1–20) → slow, smooth sweep

## READ TAP SWEEPS 48 → 48+depth SAMPLES BACK

Continuously varying delay detunes the wet copy — that shimmer mixed 50/50 with the dry signal is the chorus.

### Per-sample (ISR)

tri = triangle(lfoPhase)
lfoPhase += rate
tap = 48 + (tri*depth>>8)
wet = buf[w - tap]
y = (x>>1) + (wet>>1)
// 50 / 50 dry+wet
// no feedback path

depth 1–48 samples
rate 1–20 · sets sweep speed

# Reverb — 10 fixed taps

## 10 EQUAL-WEIGHT REFLECTIONS · sum >> 3

dry | 73 | 487

Taps 73 → 487 samples ≈ 7.6 – 50.7 ms — dense pattern, not 10 discrete echoes

### Per-sample mix

rev = (t1+t2+...+t10)
>> 3;
store = x + rev*fb >> 8;
out = x + rev*mix >> 8;
// recursive → dense tail

### STABILITY GATE

10 · (1/8) · fb/256 < 1
→ feedback < 205, else self-oscillation. Default 190 ≈ 300 ms half-life (medium room).

# Tuner — AMDF pitch detection

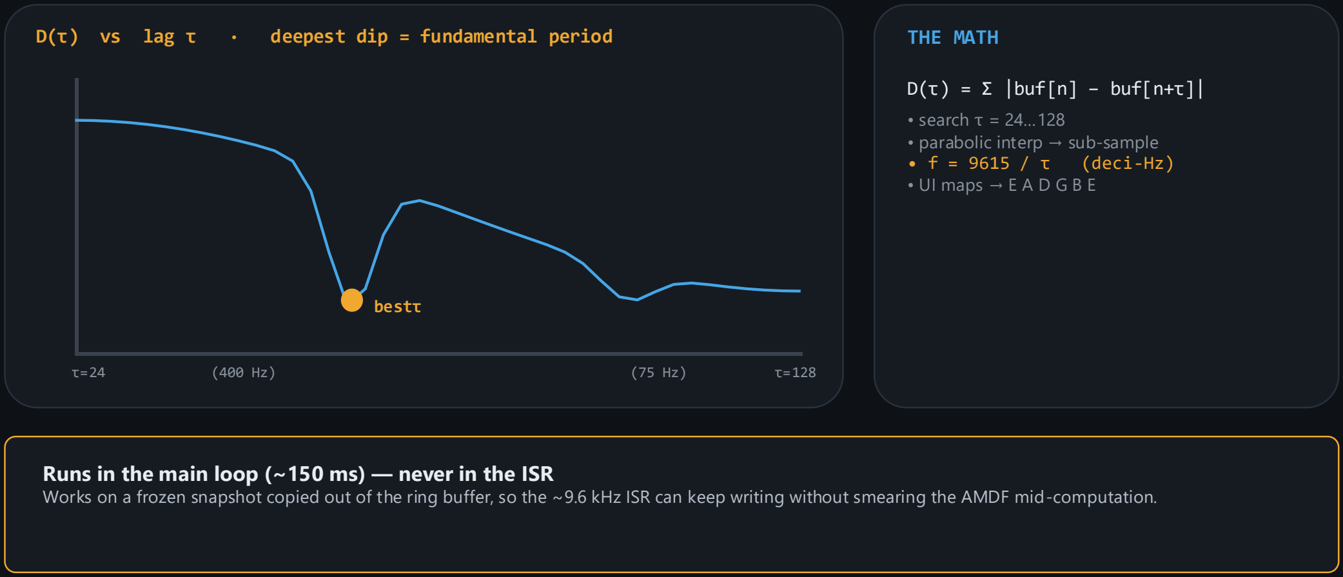
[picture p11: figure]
bestτ; THE MATH; D(τ) = Σ |buf[n] − buf[n+τ]|; • search τ = 24…128 • parabolic interp → sub-sample; (deci-Hz); • UI maps → E A D G B E

D(τ) vs lag τ | · | deepest dip = fundamental period

### Runs in the main loop (~150 ms) — never in the ISR

Works on a frozen snapshot copied out of the ring buffer, so the ~9.6 kHz ISR can keep writing without smearing the AMDF mid-computation.

# Auto-VGA — main-loop AGC

## PEAK → GAIN RESPONSE

### peak > 380

HIGH | step gain DOWN

40 – 380
DEF=15 | hold (sweet spot)

8 – 40
LOW | step gain UP

### peak < 8

NOISE | noise floor · never boost

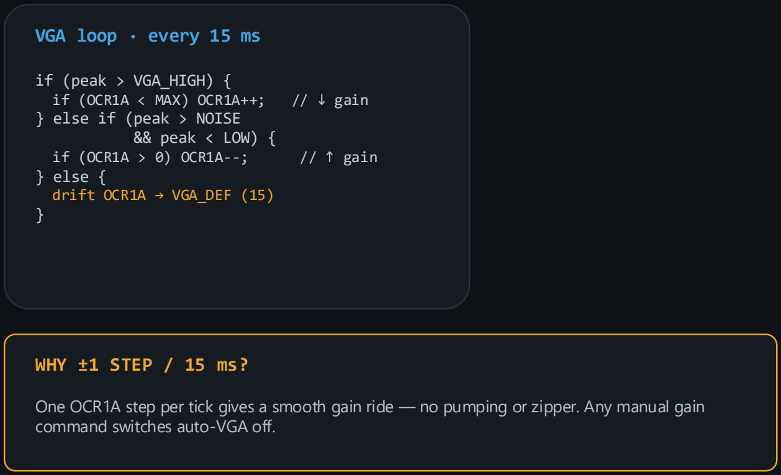
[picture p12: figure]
VGA loop · every 15 ms; if (peak > VGA_HIGH) {; if (OCR1A < MAX) OCR1A++;; // ↓ gain; } else if (peak > NOISE && peak < LOW) {; if (OCR1A > 0) OCR1A--;; // ↑ gain; } else { drift OCR1A → VGA_DEF (15); WHY ±1 STEP / 15 ms?; command switches auto-VGA off.

One OCR1A step per tick gives a smooth gain ride — no pumping or zipper. Any manual gain

↓

## SECTION 03

# Backend

# FastAPI + Whisper STT + LLM tone engine

# Backend architecture — FastAPI

## API ENDPOINTS · app/main.py

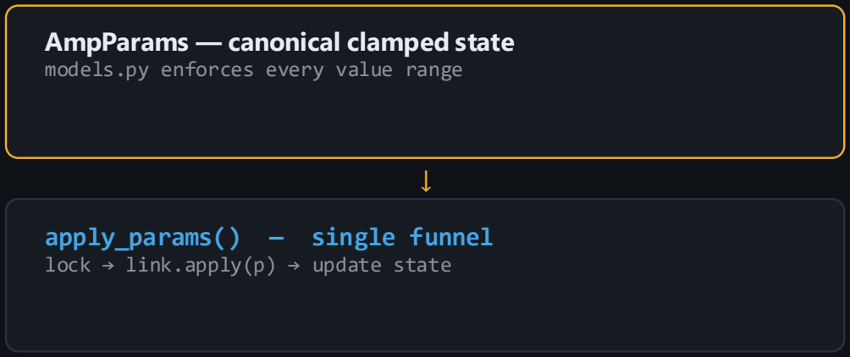
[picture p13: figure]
AmpParams — canonical clamped state models.py enforces every value range; apply_params() — single funnel lock → link.apply(p) → update state

GET | /api/state current AmpParams + effect name
POST | /api/params apply a full manual update
POST | /api/chat one tone-engine turn → board
POST | /api/transcribe browser audio → Whisper text
GET | /api/telemetry SSE stream · ~10 Hz

## REQUEST → BOARD

SF4Link
real serial

↓

# Serial protocol — one atomic frame

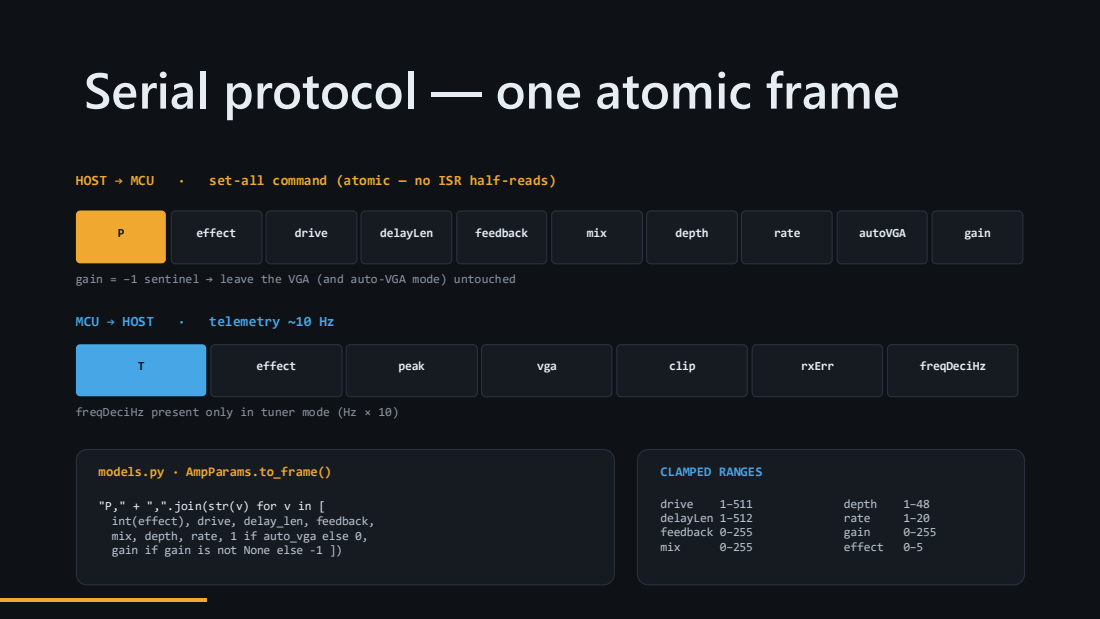
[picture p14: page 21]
HOST → MCU; set-all command (atomic — no ISR half-reads); effect; drive; delayLen; feedback; mix; depth; rate; autoVGA; gain; MCU → HOST; telemetry ~10 Hz; peak; vga; clip; rxErr; freqDeciHz; CLAMPED RANGES; delayLen 1–512 feedback 0–255

gain = −1 sentinel → leave the VGA (and auto-VGA mode) untouched

freqDeciHz present only in tuner mode (Hz × 10)

models.py · AmpParams.to_frame()

"P," + ",".join(str(v) for v in [
int(effect), drive, delay_len, feedback,
mix, depth, rate, 1 if auto_vga else 0,
gain if gain is not None else -1 ])

# Voice input — Whisper STT

## VOICE PIPELINE

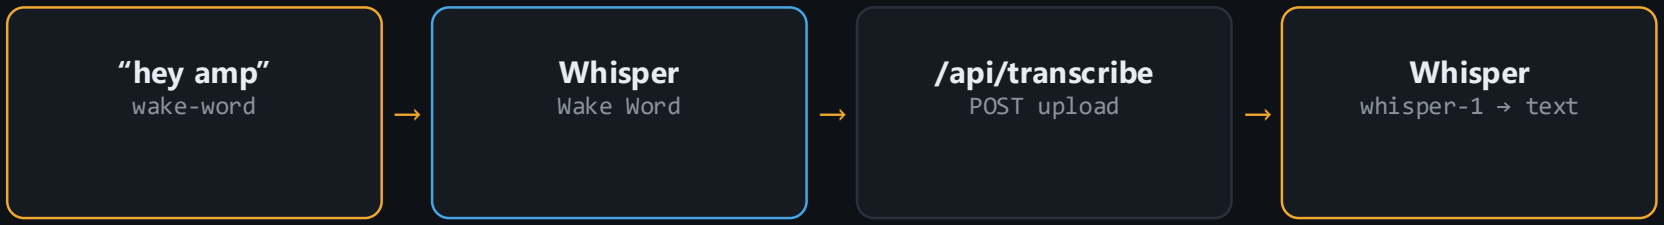
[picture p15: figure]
“hey amp”; wake-word; Whisper; Wake Word; /api/transcribe; POST upload; Whisper whisper-1 → text

### /api/transcribe (FastAPI)

raw = await file.read()
buf = io.BytesIO(raw)
buf.name = "recording.webm"
txt = client.audio.transcriptions.create( model="whisper-1", file=buf, language="en").text

## NOTES

Returns text only
The transcript goes to the chat endpoint as a normal user turn.
Model configurable
OPENAI_TRANSCRIBE_MODEL env override.

# LLM tone engine — system prompt

tone_engine.py · SYSTEM_PROMPT

You are the tone engine for the SF4 guitar amp. You translate a player's request into amp settings by calling the set_amp_params tool.

EFFECTS (one active at a time):
clean | - no processing
overdrive - drive 1..511 (16 breakup,
| 180 rock, 480 metal)
delay | - delay_len 1..512, feedback, mix
| (t = delay_len/9615 Hz, <=53 ms)
chorus | - depth 1..48, rate 1..20
reverb | - feedback (KEEP < 205 or it
| self-oscillates), mix
tuner | - clean passthrough; UI shows EADGBE

auto_vga defaults true; manual gain 0..255.

GUIDELINES
- Tone-setting requests are ACTION requests, not questions -> you MUST call set_amp_params before replying.
- Pick the single best effect for the request.
- Change only the fields that matter; edits are relative to the CURRENT settings.
- Purely factual questions: answer, no tool.
- Keep spoken replies short.

## KEY RULES

Action, not chat
“Tone-setting requests are action requests, not questions” — the model must call the tool before it speaks.

Relative edits
Patches merge onto current state — “more drive” nudges, not resets.

Guardrails in the prompt
reverb feedback < 205, one effect at a time — the LLM is told the safe ranges.

# LLM tone engine — tools & flow

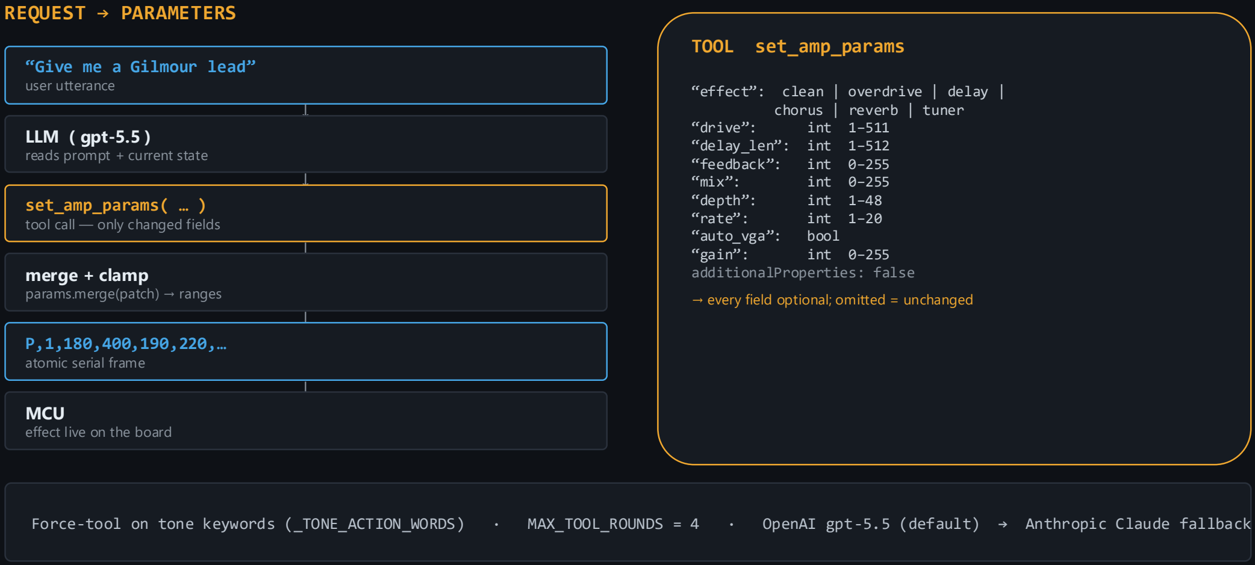
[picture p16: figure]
REQUEST → PARAMETERS; “Give me a Gilmour lead”; user utterance; LLM ( gpt-5.5 ) reads prompt + current state; set_amp_params( … ); tool call — only changed fields; merge + clamp params.merge(patch) → ranges; atomic serial frame; MCU effect live on the board; TOOL set_amp_params; “effect”: clean | overdrive | delay | chorus | reverb | tuner; “drive”:; int 1–511; “delay_len”: int 1–512; “feedback”:; int 0–255; “mix”:; “depth”:; int 1–48; “rate”:; int 1–20; “auto_vga”:; bool; “gain”:; additionalProperties: false

→ every field optional; omitted = unchanged

Force-tool on tone keywords (_TONE_ACTION_WORDS) | · | MAX_TOOL_ROUNDS = 4 | · | OpenAI gpt-5.5 (default) → Anthropic Claude fallback

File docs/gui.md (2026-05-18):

# 08 — Python GUI

## Overview

The dashboard is built with **PyQt5** and **pyqtgraph**. PyQtgraph renders plots at > 60 fps without blocking the GUI — matplotlib cannot do this for live streaming data. The layout has four panels: live waveform, rolling spectrogram, metrics summary, and LLM commentary feed.

---

## Installation

```bash
pip install pyqtgraph PyQt5 numpy
```

---

## Layout

```
┌──────────────────────────┬──────────────────────────────────┐
│  LIVE WAVEFORM           │  METRICS                         │
│  (piezo channel, A0)     │  Breathing rate:  14.2 br/min    │
│  scrolling 2.56-s window │  Regularity:      0.74           │
│                          │  I:E ratio:       0.58           │
│                          │  Apnea:           No             │
├──────────────────────────│  SpO2:            — (extension)  │
│  SPECTROGRAM             │  Heart rate:      — (extension)  │
│  (time × frequency)      │  Pattern:  NORMAL (81%)          │
│  colour = power          │                                  │
│  y-axis 0–4 Hz           ├──────────────────────────────────┤
│                          │  SEVERITY   ●●○○  Mild concern   │
│                          │  Biofeedback: 6 br/min  ●        │
├──────────────────────────├──────────────────────────────────┤
│  [▶ Start] [■ Stop]      │  AI COMMENTARY                   │
│  Mode: [EXERCISE ▼]      │  Rate elevated at 28 br/min,     │
│  [⬇ Export Report]       │  consistent with moderate effort.│
│                          │  ─────────────────────────────   │
│                          │  ▶ Maintain current pace.        │
└──────────────────────────┴──────────────────────────────────┘
```

---

## Full GUI Implementation

```python
# python/gui.py

import sys, time
import numpy as np
import pyqtgraph as pg
from PyQt5.QtWidgets import (
    QApplication, QMainWindow, QWidget,
    QVBoxLayout, QHBoxLayout, QLabel,
    QPushButton, QComboBox, QTextEdit, QGridLayout
)
from PyQt5.QtCore import QTimer, Qt
from PyQt5.QtGui import QFont

from serial_handler import SerialHandler
from feature_extractor import parse_data_packet
from classifier import BreathingClassifier
from llm_client import LLMClient, apply_llm_response

SEVERITY_COLOURS = {0: "#27ae60", 1: "#e67e22", 2: "#e74c3c", 3: "#c0392b"}
SEVERITY_LABELS  = {0: "Normal", 1: "Mild concern", 2: "Alert", 3: "Urgent"}

class Dashboard(QMainWindow):
    def __init__(self, serial: SerialHandler, clf: BreathingClassifier, llm: LLMClient):
        super().__init__()
        self.serial  = serial
        self.clf     = clf
        self.llm     = llm
        self.mode    = "EXERCISE"
        self.running = False
        self.session_start = None

        # Data buffers
        self.waveform  = np.zeros(256)
        self.br_hist   = []   # breathing rate over session
        self.t_hist    = []   # timestamps
        self.spec_buf  = np.zeros((16, 60))  # 16 freq bins × 60 time steps

        pg.setConfigOption('background', '#1a1a2e')
        pg.setConfigOption('foreground', '#e0e0e0')

        self._build_ui()
        self._start_timers()

    # ── UI construction ──────────────────────────────────────────────────────

    def _build_ui(self):
        self.setWindowTitle("Respiratory Fitness Monitor")
        self.setMinimumSize(1050, 680)

        central = QWidget()
        self.setCentralWidget(central)
        root = QHBoxLayout(central)

        left  = QVBoxLayout()
        right = QVBoxLayout()
        root.addLayout(left,  stretch=3)
        root.addLayout(right, stretch=2)

        self._add_waveform(left)
        self._add_spectrogram(left)
        self._add_controls(left)
        self._add_metrics(right)
        self._add_llm_panel(right)

    def _add_waveform(self, layout):
        self.wave_plot = pg.PlotWidget(title="Live Breathing Waveform (piezo)")
        self.wave_plot.setLabel('left',   'ADC (zero-centred)')
        self.wave_plot.setLabel('bottom', 'Sample (100 Hz)')
        self.wave_plot.setYRange(-512, 512)
        self.wave_curve = self.wave_plot.plot(pen=pg.mkPen('#4fc3f7', width=2))
        layout.addWidget(self.wave_plot)

    def _add_spectrogram(self, layout):
        self.spec_plot = pg.PlotWidget(title="Rolling Spectrogram (0–4 Hz)")
        self.spec_plot.setLabel('left',   'Frequency (Hz)')
        self.spec_plot.setLabel('bottom', 'Time →')
        self.spec_img  = pg.ImageItem()
        self.spec_plot.addItem(self.spec_img)
        self.spec_img.setColorMap(pg.colormap.get('CET-L9'))
        self.spec_plot.setYRange(0, 4)
        layout.addWidget(self.spec_plot)

    def _add_controls(self, layout):
        row = QHBoxLayout()

        self.mode_cb = QComboBox()
        self.mode_cb.addItems(["EXERCISE", "STRESS", "PASSIVE"])
        self.mode_cb.currentTextChanged.connect(lambda m: setattr(self, 'mode', m))
        row.addWidget(QLabel("Mode:"))
        row.addWidget(self.mode_cb)

        self.btn_start = QPushButton("▶  Start")
        self.btn_start.setStyleSheet("background:#27ae60;color:white;font-weight:bold;padding:8px")
        self.btn_start.clicked.connect(self._on_start)
        row.addWidget(self.btn_start)

        self.btn_stop = QPushButton("■  Stop")
        self.btn_stop.setEnabled(False)
        self.btn_stop.clicked.connect(self._on_stop)
        row.addWidget(self.btn_stop)

        btn_export = QPushButton("⬇  Export")
        btn_export.clicked.connect(self._on_export)
        row.addWidget(btn_export)

        layout.addLayout(row)

    def _add_metrics(self, layout):
        layout.addWidget(self._separator("── Live Metrics ──"))

        grid = QGridLayout()
        self._mv = {}
        rows = [
            ("Breathing rate", "—"),
            ("Regularity",     "—"),
            ("I:E ratio",      "—"),
            ("Apnea",          "—"),
            ("SpO₂",           "— (ext.)"),
            ("Heart rate",     "— (ext.)"),
            ("Pattern",        "—"),
        ]
        for i, (lbl, default) in enumerate(rows):
            ql = QLabel(lbl);   ql.setFont(QFont("Arial", 10))
            qv = QLabel(default); qv.setFont(QFont("Courier", 16))
            qv.setStyleSheet("color:#4fc3f7")
            grid.addWidget(ql, i, 0)
            grid.addWidget(qv, i, 1)
            self._mv[lbl] = qv
        layout.addLayout(grid)

        layout.addWidget(self._separator("── Status ──"))
        self.sev_label = QLabel("● Normal")
        self.sev_label.setFont(QFont("Arial", 13, QFont.Bold))
        self.sev_label.setStyleSheet(f"color:{SEVERITY_COLOURS[0]}")
        layout.addWidget(self.sev_label)

        self.bf_label = QLabel("Biofeedback: OFF")
        self.bf_label.setFont(QFont("Arial", 11))
        layout.addWidget(self.bf_label)

    def _add_llm_panel(self, layout):
        layout.addWidget(self._separator("── AI Commentary ──"))
        self.llm_box = QTextEdit()
        self.llm_box.setReadOnly(True)
        self.llm_box.setFont(QFont("Arial", 11))
        self.llm_box.setStyleSheet(
            "background:#12122a;color:#e0e0e0;border:1px solid #333;padding:4px"
        )
        self.llm_box.setMinimumHeight(160)
        layout.addWidget(self.llm_box)

        self.advice_label = QLabel("")
        self.advice_label.setWordWrap(True)
        self.advice_label.setFont(QFont("Arial", 11, QFont.Bold))
        self.advice_label.setStyleSheet("color:#f39c12;padding:6px")
        layout.addWidget(self.advice_label)

    def _separator(self, text: str) -> QLabel:
        lbl = QLabel(text)
        lbl.setFont(QFont("Arial", 9))
        lbl.setStyleSheet("color:#888;margin-top:6px")
        return lbl

    # ── Timers ───────────────────────────────────────────────────────────────

    def _start_timers(self):
        self._serial_timer = QTimer()
        self._serial_timer.timeout.connect(self._drain_serial)
        self._serial_timer.start(100)   # poll serial every 100 ms

        self._plot_timer = QTimer()
        self._plot_timer.timeout.connect(self._refresh_plots)
        self._plot_timer.start(200)     # redraw every 200 ms

    # ── Session controls ─────────────────────────────────────────────────────

    def _on_start(self):
        self.running       = True
        self.session_start = time.time()
        self.btn_start.setEnabled(False)
        self.btn_stop.setEnabled(True)
        self.llm_box.clear()
        self.llm_box.append(f"Session started — mode: {self.mode}\n")

    def _on_stop(self):
        self.running = False
        self.btn_start.setEnabled(True)
        self.btn_stop.setEnabled(False)
        for cmd in ("CMD:SEV:0", "CMD:BF:0", "CMD:ALERT:0"):
            self.serial.send(cmd)

    def _on_export(self):
        summary  = self.llm.session_summary()
        filename = f"session_{int(time.time())}.txt"
        with open(filename, 'w') as f:
            f.write(summary)
        self.llm_box.append(f"\n[Report saved → {filename}]")

    # ── Data handling ─────────────────────────────────────────────────────────

    def _drain_serial(self):
        while True:
            msg = self.serial.get_message()
            if msg is None:
                break
            self._handle_message(msg)

    def _handle_message(self, msg: str):
        feat = parse_data_packet(msg)
        if feat is None:
            return

        bpm = feat.breathing_rate * 60.0
        self._mv["Breathing rate"].setText(f"{bpm:.1f} br/min")
        self._mv["Regularity"].setText(f"{feat.regularity:.2f}")
        self._mv["I:E ratio"].setText(f"{feat.ie_ratio:.2f}")
        self._mv["Apnea"].setText("⚠ YES" if feat.apnea_flag else "No")

        if feat.spo2 is not None:
            self._mv["SpO₂"].setText(f"{feat.spo2:.1f}%")
            self._mv["Heart rate"].setText(f"{feat.heart_rate:.0f} bpm")

        if feat.apnea_flag:
            self.serial.send("CMD:ALERT:1")
            self.llm_box.append("\n⚠ APNEA EVENT DETECTED")

        if not self.running:
            return

        result  = self.clf.predict(feat)
        cls_lbl = result['class'].replace('_', ' ').title()
        conf    = result['confidence'] * 100
        self._mv["Pattern"].setText(f"{cls_lbl} ({conf:.0f}%)")

        elapsed = (time.time() - self.session_start) / 60.0
        self.br_hist.append(bpm)
        self.t_hist.append(elapsed)

        llm_resp = self.llm.interpret(feat, result, self.mode, elapsed)
        if llm_resp:
            self._apply_llm(llm_resp)

    def _apply_llm(self, resp):
        self.llm_box.append(f"\n{resp.commentary}")
        self.advice_label.setText(f"▶ {resp.advice}")

        colour = SEVERITY_COLOURS.get(resp.severity, SEVERITY_COLOURS[0])
        self.sev_label.setText(f"● {SEVERITY_LABELS[resp.severity]}")
        self.sev_label.setStyleSheet(f"color:{colour}")

        self.bf_label.setText(
            f"Biofeedback: {resp.biofeedback_rate} br/min ●"
            if resp.biofeedback_rate > 0 else "Biofeedback: OFF"
        )
        apply_llm_response(resp, self.serial)

    def _refresh_plots(self):
        self.wave_curve.setData(self.waveform)
        if self.br_hist:
            self.spec_buf = np.roll(self.spec_buf, -1, axis=1)
            # Spectrogram column populated from FFT bins if sent by Arduino
            self.spec_img.setImage(self.spec_buf.T, autoLevels=False, levels=(0, 300))

    def run(self):
        app = QApplication.instance() or QApplication(sys.argv)
        self.show()
        sys.exit(app.exec_())
```

---

## Extending the Spectrogram

To populate the spectrogram meaningfully, extend the Arduino serial packet to include 16 FFT bins:

```
DATA,<br>,<power>,<reg>,<ie>,<apnea>,<b1>,<b2>,...,<b16>\n
```

In the Python parser:

```python
if len(parts) >= 22:
    spectrum = [float(parts[6 + i]) for i in range(16)]
    # Insert as new column in spectrogram buffer
    self.spec_buf[:, -1] = spectrum
```

This adds ~80 bytes per packet (16 short integers as ASCII), well within the 115200 baud capacity.

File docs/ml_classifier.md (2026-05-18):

# Machine Learning Classifier

## Overview

A scikit-learn **Random Forest** classifies the current breathing pattern from the feature vector streamed by the Arduino. The model is trained offline during week 1–2 using labelled data you collect yourself, then saved and loaded at runtime for real-time inference.

Random Forest is chosen because it handles small datasets well, produces directly interpretable feature importances, and requires no GPU. Inference takes ~1 ms on any laptop.

---
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

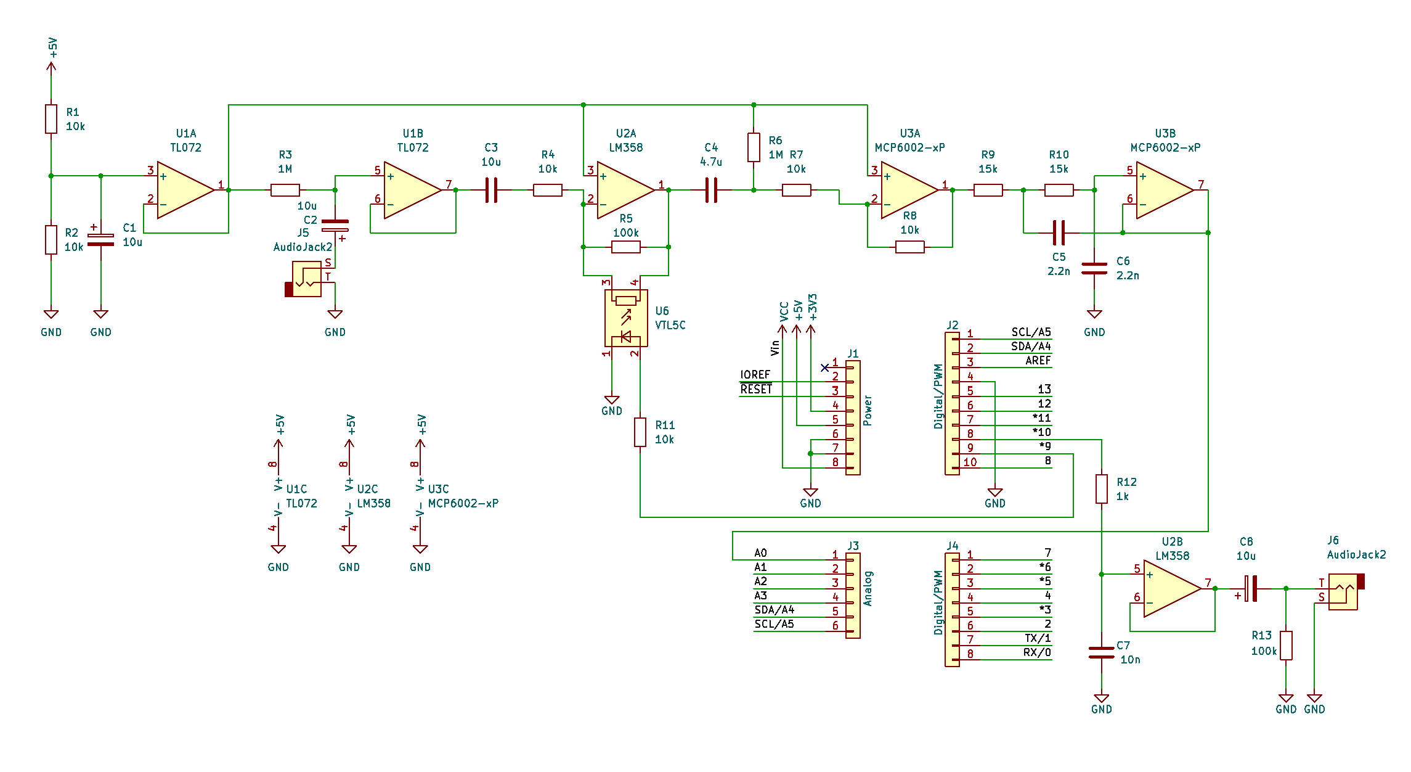
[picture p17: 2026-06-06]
schematics/KiCad/schematic.png

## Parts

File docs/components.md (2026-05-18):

# Components and Budget

## Core System Components (Must Purchase)

---

### 1. Piezoelectric Film Sensor

**Manufacturer:** TE Connectivity  
**Manufacturer P/N:** LDT1-028K  
**Description:** PVDF piezoelectric film sensor with 12-inch pre-attached wire leads. The wire leads are essential — the LDT0-028K has only crimped contacts and cannot be connected to a breadboard directly. When flexed by chest expansion during breathing, the film generates a voltage proportional to bending strain. Worn inside an elastic chest belt.

> This part appears under two Farnell order codes. Both resolve to the same LDT1-028K sensor with wire leads. Use whichever is in stock.

**Primary Onecall / Farnell order code: 2930739**  
Manufacturer P/N on this listing: 11028414-00 (TE Connectivity alternate P/N for LDT1-028K)  
**URL:** https://uk.farnell.com/te-connectivity/11028414-00/piezoelectric-sensor-vibration/dp/2930739

**Alternate Onecall / Farnell order code: 2771907**  
Also maps to LDT1-028K in Farnell catalogues.  
**URL:** https://uk.farnell.com/sensor-solutions-te-connectivity/ldt1-028k/piezoelectric-sensor-voltage-1/dp/2771907

**If in doubt:** tell the technicians to search `LDT1-028K` on Onecall and use whichever order code (2930739 or 2771907) is currently in stock.

**Public Farnell price:** ~£6.33 ex VAT (1 unit)  
**Estimated Onecall price:** ~£5.13  
**Quantity:** 1

---

### 2. NTC Thermistor 10 kΩ — Nasal Airflow Channel

**Manufacturer:** Vishay  
**Manufacturer P/N:** 2322 640 63103  
**Description:** Radial-leaded NTC disc thermistor, 10 kΩ at 25°C, B-constant ~3977 K, 17 mm tinned copper leads, 5% tolerance. Placed near one nostril in a small foam holder. Exhaled air (~34°C) lowers resistance; inhaled ambient air (~20°C) raises it, producing a clear voltage oscillation at the breathing rate via a simple resistor voltage divider. No amplification needed.

**Onecall / CPC order code: SN35070**  
**URL:** https://cpc.farnell.com/vishay/2322-640-63103/thermistor-ntc-10k-5/dp/SN35070

**Public CPC price:** £0.28 ex VAT (1 unit), £0.24 for 10+  
**Estimated Onecall price:** ~£0.23  
**Quantity:** 2 (one spare — leads are fragile)

---

### 3. RGB LED 5mm Common Cathode

**Manufacturer:** Pro Signal  
**Manufacturer P/N:** PSG91924  
**Description:** Pack of 3 × 5mm diffused RGB LEDs, common cathode. Four pins per LED: red (Vf ≈ 2.1V, 50mA max), green (Vf ≈ 3.1V, 30mA max), blue (Vf ≈ 3.1V, 30mA max), and shared cathode (longest pin). Driven from Arduino PWM pins D9/D10/D11 via current-limiting resistors. Displays exercise intensity and alert state as colour: green / amber / red.

> Note: the CPC product page currently reads "price for: pack of 5" in the pricing label, but the product itself is still a pack of 3 LEDs as stated in the description. You receive 3 LEDs per pack.

**Onecall / CPC order code: SC19718**  
**URL:** https://cpc.farnell.com/pro-signal/psg91924/led-5mm-r-g-b-com-cath-diffused/dp/SC19718

**Public CPC price:** £1.75 ex VAT (pack of 3)  
**Estimated Onecall price:** ~£1.42  
**Quantity:** 1 pack

---

## Core Budget Summary

| # | Component | Manufacturer P/N | Onecall Code | Public Price | Est. Onecall Price |
|---|---|---|---|---|---|
| 1 | LDT1-028K piezo sensor | LDT1-028K | 2930739 (or 2771907) | £6.33 | ~£5.13 |
| 2 | NTC thermistor 10 kΩ × 2 | 2322 640 63103 | SN35070 | £0.56 | ~£0.46 |
| 3 | RGB LED pack of 3 | PSG91924 | SC19718 | £1.75 | ~£1.42 |
| **Total** | | | | **£8.64** | **~£7.01** |

Leaves approximately **£6–8 of the £15 budget** for the optional SpO2 extension and/or LCD.

---

## Lab Stock — Free (Confirm with Technicians Before Ordering)

If any of these are not in lab stock, add them to the Onecall order at that point.

| Component | Value / Part | Purpose |
|---|---|---|
| LM358 dual op-amp, DIP-8 | LM358P or LM358N | Op-amp front-end. **Must be LM358 — not TL072.** The TL072 requires ±3.5V minimum supply and will not work from the Arduino's 5V rail. |
| Resistors | 1 MΩ, 100 kΩ, 33 kΩ, 10 kΩ, 4.7 kΩ, 2.2 kΩ, 1 kΩ, 220 Ω, 150 Ω | Filter, gain, bias network, LED current-limiting |
| Ceramic capacitors | 100 nF × 4, 10 nF × 2 | Decoupling, filter poles |
| Electrolytic capacitors | 10 µF × 2, 1 µF × 1 | DC coupling, filter |
| Green LED 5mm | Any | Biofeedback pacer (D6) |
| Active piezo buzzer, 5V | Self-drive type | Apnea alert (D7) |
| Resettable polyfuse | 200 mA | USB port protection — required |
| Jumper wires M-M | Assorted lengths | Breadboard-to-Arduino connections |
| Breadboard | 830-point | Circuit construction |

---

## Optional Extension A — DIY PPG: BPW34 + TSAL6400 (~£1 total)

Add after the core system is verified working. Gives heart rate and a secondary PPG-derived breathing signal. Does **not** give SpO2 (that requires two LED wavelengths with a more complex front-end).

**Advantage over Option B:** you design the transimpedance amplifier from scratch, which is genuine analogue circuit work scoring additional marks on the analogue design criterion.

---

### BPW34 Silicon PIN Photodiode

**Manufacturer:** Vishay  
**Manufacturer P/N:** BPW34  
**Description:** Silicon PIN photodiode, 900nm peak sensitivity, 7.5mm² active area, ±65° half-angle, 2nA dark current. Used as the detector in the PPG front-end with a transimpedance amplifier (LM358).

> The previously listed order code 1497753 is incorrect/obsolete. Use one of the two verified codes below.

**Option 1 — CPC / Onecall:**  
Order code: **SC07697**  
URL: https://cpc.farnell.com/vishay/bpw34/photodiode/dp/SC07697

**Option 2 — Farnell UK / Onecall:**  
Order code: **1045425**  
URL: https://uk.farnell.com/vishay/bpw34/silicon-pin-diode-900nm-65deg/dp/1045425

**Quantity:** 1

---

### TSAL6400 940nm IR LED

**Manufacturer:** Vishay  
**Manufacturer P/N:** TSAL6400  
**Description:** 940nm peak wavelength IR emitter, 5mm T-1 3/4 package, ~1.35V forward voltage, high radiant intensity, optimised for pairing with IR photodiode receivers. Used to illuminate the finger in the PPG circuit.

**Onecall / Farnell order code: 1652530**  
**URL:** https://uk.farnell.com/vishay/tsal6400/infrared-emitter-940nm-t-1-3-4/dp/1652530

**Public Farnell price:** ~£0.25–0.35 ex VAT  
**Quantity:** 1

---

**Total cost for Option A: ~£0.70–0.90 on Onecall**

---

## Optional Extension B — GY-MAX30100 SpO2 Module (~£2–3)

Gives true SpO2, heart rate, and PPG waveform via I2C. Drop-in module with an existing Arduino library, lower circuit complexity than Option A but no additional analogue design marks.

**⚠ Not available on Onecall, Farnell, or CPC.** Purchase separately:

- **eBay UK:** search `GY-MAX30100 Arduino` — https://www.ebay.co.uk
- **Amazon UK:** search `MAX30100 sensor module Arduino` — https://www.amazon.co.uk

Typical price: **£2.00–£3.50 delivered** from UK sellers.

> Buy the **green PCB (GY-MAX30100)** variant. Avoid the purple RCWL-0530 board — it has a known hardware design error requiring a resistor modification before it will work.

**Arduino library:** `MAX30100lib` by OXullo Intersecans (Arduino Library Manager)  
**I2C address:** 0x57 | **Power:** 3.3V Arduino pin  
**Pins used:** A4 (SDA), A5 (SCL) — shared I2C bus with LCD

---

## Optional Addition — 16×2 LCD with I2C Backpack (~£2–4)

Displays live breathing rate and status text on the hardware unit without requiring the PC screen.

Search `LCD 1602 I2C` directly on https://onecall.farnell.com — multiple compatible modules are available. Confirm the I2C address (typically 0x27 or 0x3F) by running the I2C scanner sketch in doc 09 before writing any LCD firmware.

---

## Full Budget Scenarios

| Scenario | Est. Onecall (core) | Extension | LCD | Total |
|---|---|---|---|---|
| Core only | ~£7.01 | — | — | **~£7.01** |
| Core + Option A (DIY PPG) | ~£7.01 | ~£0.80 | — | **~£7.81** |
| Core + Option B (GY-MAX30100) | ~£7.01 | £2–3.50 (eBay) | — | **~£9–10.50** |
| Core + Option B + LCD | ~£7.01 | £2–3.50 | ~£3 | **~£12–13.50** |

All scenarios remain within the £15 budget.

---

## Summary for Lab Technicians (Order Form)

| Component | Manufacturer P/N | Onecall / CPC Code | Qty |
|---|---|---|---|
| Piezo film sensor with wire leads | LDT1-028K | **2930739** (alt: 2771907) | 1 |
| NTC thermistor 10 kΩ | 2322 640 63103 | **SN35070** | 2 |
| RGB LED 5mm common cathode, pack of 3 | PSG91924 | **SC19718** | 1 |
| *If adding PPG extension:* | | | |
| BPW34 photodiode | BPW34 | **SC07697** or **1045425** | 1 |
| 940nm IR LED | TSAL6400 | **1652530** | 1 |

---

## Ordering Procedure

1. Verify stock availability and lead times on each Onecall product page — avoid items showing "US stock" (multi-week lead times)
2. Download and check the datasheet for each component before submitting
3. Discuss the final list with a demonstrator — they must approve it
4. Fill in the EIETL component order form using the codes above
5. Submit to lab technicians — standard UK stock arrives in 1–2 working days
6. **Order as early as possible** — do not wait until the interim report deadline

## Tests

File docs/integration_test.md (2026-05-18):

# System Integration and Testing

## Build Order

Build and test one subsystem at a time. Never connect an untested part to working circuitry — you will not know which part caused a failure.

```
Step 1:  Power rails and polyfuse
Step 2:  Thermistor voltage divider
Step 3:  Op-amp bias circuit (no piezo)
Step 4:  Op-amp with piezo connected
Step 5:  Full Arduino firmware — serial output only
Step 6:  LED outputs (RGB, pacer)
Step 7:  Buzzer
Step 8:  LCD
Step 9:  Python serial receive + data parsing
Step 10: ML classifier integration
Step 11: LLM integration
Step 12: Full system demonstration rehearsal
Step 13: (Optional) SpO2 extension
```

---

## Step 1 — Power Rails

Before placing any components:

1. Connect Arduino 5V → breadboard positive rail, GND → negative rail
2. Measure with multimeter: **5.0V ± 0.1V** across rails
3. Wire polyfuse in series with 5V: verify continuity through it (< 5 Ω)
4. Place 100 nF decoupling cap across rails at the centre of the board

**Pass:** 5V present, polyfuse shows continuity.

---

## Step 2 — Thermistor Channel

Build the voltage divider and RC filter; connect to A1. Upload:

```cpp
void setup() { Serial.begin(115200); }
void loop()  { Serial.println(analogRead(A1)); delay(100); }
```

Open Serial Monitor at 115200 baud.

| Condition | Expected ADC | Reason |
|---|---|---|
| Room temp ~21°C | 510–530 | NTC slightly above 10 kΩ at 21°C |
| Hold thermistor (finger, ~36°C) | ~400 | NTC resistance drops, divider output drops |
| Blow cold air on thermistor | ~560–580 | NTC resistance rises |

**Pass:** ADC around 520 at rest; measurably decreases when warmed, increases when cooled.

---

## Step 3 — Op-Amp Bias (No Piezo)

1. Build the voltage divider for 2.5V bias (two 10 kΩ resistors, 5V to GND)
2. Wire LM358A as a voltage follower (pin 2 → pin 1, pin 3 → bias)
3. Build the Stage 2 inverting amplifier with 2.5V on pin 5
4. Measure at each op-amp output pin with multimeter

| Point | Expected voltage |
|---|---|
| Bias node | 2.5V ± 0.05V |
| LM358A pin 1 (follower out) | 2.5V ± 0.1V |
| LM358B pin 7 (amp out) | 2.5V ± 0.3V |

**Pass:** Both op-amp outputs rest near 2.5V.

If an output is stuck at 0V or 5V (saturation):
- Check LM358 pin 8 = 5V, pin 4 = 0V
- Verify feedback path: pin 1 → pin 2 for Stage 1
- Check decoupling cap is placed correctly
- Confirm LM358, **not** TL072

---

## Step 4 — Piezo Sensor

1. Connect LDT1-028K wires to op-amp input
2. Tape sensor against chest with elastic strap — secure but not tight
3. Monitor A0 in Serial Monitor (simple `Serial.println(analogRead(A0))` sketch)

**Good signal looks like:**
```
501, 508, 519, 534, 548, 558, 556, 545, 529, 511, 497, 487, 484, 489, 499, 510, ...
```
A smooth, slow wave oscillating around 512 with amplitude 20–80 counts.

**Troubleshooting:**

| Symptom | Cause | Fix |
|---|---|---|
| Flat line at ~512 | Piezo not connected or gain stage wiring error | Recheck op-amp feedback |
| Saturated at 0 or 1023 | Gain too high or bias not working | Reduce Rf or recheck bias divider |
| 50 Hz noise visible | Long signal wires acting as antenna | Shorten wires, twist piezo leads |
| Signal only with firm pressure | Elastic strap too loose | Tighten strap; sensor must flex with breathing |
| Very small signal amplitude (<10 counts) | Gain stage not wired | Verify R3, Rf connected correctly |

---

## Step 5 — Full Firmware Serial Output

Flash the complete firmware. With no Python running, open Serial Monitor at 115200:

1. `DATA,...` packets appear every ~2.56 seconds ✓
2. Breathing rate changes when you breathe faster or slower ✓
3. Sending `CMD:SEV:2` in the Serial Monitor input field turns the RGB LED red ✓
4. Sending `CMD:BF:6` starts the pacer LED pulsing ✓

---

## Step 6–8 — Outputs

Test each output from Serial Monitor before connecting Python:

```
CMD:SEV:0     → Green LED
CMD:SEV:1     → Amber LED
CMD:SEV:2     → Red LED
CMD:SEV:3     → Flashing red

CMD:BF:6      → Pacer: one cycle per 10 seconds (slow, clear to see)
CMD:BF:20     → Pacer: approximately one cycle per 3 seconds
CMD:BF:0      → Pacer off

CMD:ALERT:1   → Buzzer: three-beep apnea pattern
CMD:ALERT:0   → Buzzer off
```

---

## Step 9 — Python Serial Integration

```bash
python collect_training_data.py normal
```

Verify the CSV file is written and contains sensible values (breathing rate ~0.2–0.3 Hz at rest).

---

## Step 10–11 — ML and LLM

1. Collect training data for all 6 classes (see doc 06)
2. Run `python train_classifier.py` — should complete in < 30 seconds
3. Test LLM independently before the full GUI:

```python
# Quick test in a Python shell:
from llm_client import LLMClient
from feature_extractor import RespiratoryFeatures
import time

client = LLMClient()
feat = RespiratoryFeatures(0.23, 1200, 0.75, 0.55, 0, time.time())
cls  = {'class': 'normal', 'confidence': 0.88,
        'probabilities': {'normal': 0.88, 'irregular': 0.12}}
resp = client.interpret(feat, cls, "EXERCISE", 5.0)
print(resp)
```

Expected: a valid `LLMResponse` with severity=0 and sensible commentary.

---

## Step 12 — Full System Demonstration Rehearsal

Run through the full demo scenario:

1. Start Python GUI, select EXERCISE mode, click Start
2. **Quiet breathing (1–2 min):** confirm class = "normal", green LED, sensible LLM commentary
3. **Exercise (2 min, e.g. walking or jumping jacks):** confirm breathing rate increases, class transitions to exercise pattern, amber/red LED if appropriate, LLM commentary updates
4. **Recovery (sit down):** confirm rate tracks downward, LLM suggests biofeedback rate, pacer LED activates
5. **Simulated apnea (hold breath ~12 seconds):** confirm buzzer sounds, GUI shows APNEA alert, severity flashes red
6. **Stop session, click Export:** confirm session summary file is written

---

## Debugging Reference Table

| Symptom | Likely cause | Fix |
|---|---|---|
| Serial Monitor shows nothing | Baud rate wrong | Set Serial Monitor to 115200 |
| Python cannot connect | Another program has port | Close Arduino Serial Monitor first |
| DATA packets stop after a few | Timer1 conflicts with `delay()` | Remove all `delay()` from loop() |
| Breathing rate always 0.39 Hz | FFT DC not removed | Subtract 512 in ISR before storing to piezoBuffer |
| LLM always returns None | API key not set | `echo $ANTHROPIC_API_KEY` to check |
| RGB LED shows wrong colour | Common cathode wired to 5V | Flip LED — cathode (longest pin) to GND |
| Op-amp output saturated | TL072 used instead of LM358 | Replace IC — TL072 cannot run from 5V |
| LCD shows garbled characters | Wrong I2C address | Run I2C scanner sketch |
| Buzzer sounds continuously | alertMode stuck | Check `CMD:ALERT:0` is being sent |
| Classifier always predicts same class | Not enough training data | Collect more sessions for minority classes |

---

## Step 13 (Optional) — SpO2 Extension

Add only after Steps 1–12 are fully verified. See doc 01 for hardware, doc 03 for firmware. After adding:

1. Run I2C scanner — confirm you see two addresses (LCD + MAX30100/30102)
2. Load the MAX30100 example sketch, verify SpO2 and HR appear in Serial Monitor
3. Update `parse_data_packet()` to handle the extra fields
4. Retrain the classifier with the new features

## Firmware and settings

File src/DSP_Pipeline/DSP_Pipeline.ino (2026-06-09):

/*
 * Arduino Uno R3 — Real-time guitar DSP
 *
 * Effects (select with 'e' command):
 *   0 = Clean      — transparent passthrough
 *   1 = Overdrive  — hard clipping
 *   2 = Delay      — single echo with feedback (~53 ms max)
 *   3 = Chorus     — triangle-LFO modulated short delay, 50/50 dry/wet
 *   4 = Reverb     — five-tap feedback network
 *
 * VGA (pin 9 / OC1A): gradual soft-limiter when too loud; gentle boost when
 *   too quiet but above the noise floor; drifts back to resting gain otherwise.
 *   Higher OCR1A = lower gain (optocoupler: brighter LED -> lower R_LDR).
 *
 * Shared audio ring buffer: 512 x int8_t = 512 B SRAM.
 *   Samples stored right-shifted by 2 (2 LSBs lost; matches 8-bit PWM output).
 *
 * ADC  : A0, free-running, prescaler 128 -> FS ~= 9.6 kHz
 *         Nyquist = 4.8 kHz, matches the analog anti-aliasing LPF cutoff exactly.
 *         Lower FS doubles the max delay/reverb time vs prescaler 64.
 * PWM  : pin 10 / OC1B, 8-bit Fast PWM, 62.5 kHz carrier -> RC filter -> out
 */

#include <stdio.h>
#include <stdlib.h>
#include <string.h>

// ─── Buffer ───────────────────────────────────────────────────────────────
#define BUF_SIZE   512
#define BUF_MASK  (BUF_SIZE - 1)
#define S_MIN    (-512)
#define S_MAX      511

// ─── Effect IDs ───────────────────────────────────────────────────────────
#define FX_CLEAN     0
#define FX_OVERDRIVE 1
#define FX_DELAY     2
#define FX_CHORUS    3
#define FX_REVERB    4
#define FX_TUNER     5   // clean passthrough + fundamental-pitch detection

// ─── Parameter bank (written by loop(), read by ISR) ──────────────────────
struct Params {
  uint8_t  effect;    // FX_*
  int16_t  thresh;    // overdrive: clip threshold (1..511)
  uint16_t delayLen;  // delay: tap distance in samples (1..512)
  uint8_t  feedback;  // delay/reverb: regeneration Q8 (0..255)
  uint8_t  mix;       // delay/reverb: wet level Q8 (0..255)
  uint8_t  depth;     // chorus: LFO modulation depth in samples (1..48)
  uint8_t  rate;      // chorus: LFO phase increment per sample (1..20)
};

volatile Params P = {
  FX_CLEAN,
  180,   // thresh    (drive level: 16=breakup, 180=rock, 480=metal)
  400,   // delayLen  (~41.6 ms at 9615 Hz — perceptible slapback)
  190,   // feedback
  220,   // mix
  24,    // depth
  8,     // rate  (~0.85 Hz LFO at 9615 Hz, same feel as rate=4 at 19230 Hz)
};

// ─── Shared audio ring buffer ─────────────────────────────────────────────
static int8_t   audioBuf[BUF_SIZE];
static uint16_t wIdx = 0;

// ─── Chorus LFO ───────────────────────────────────────────────────────────
static uint16_t lfoPhase = 0;

// ─── Telemetry / VGA ──────────────────────────────────────────────────────
volatile int16_t g_peak  = 0;
volatile uint8_t g_clip  = 0;
uint16_t         g_rxErr = 0;
bool             g_autoVGA = true;

// ─── Tuner ────────────────────────────────────────────────────────────────
// Detected fundamental in deci-Hz (Hz x 10); 0 = no pitch / not in tuner mode.
volatile uint16_t g_freqDeciHz = 0;

// ═══════════════════════════════════════════════════════════════════════════
//  processEffect — called from ADC ISR, one sample per call (~52 µs budget)
// ═══════════════════════════════════════════════════════════════════════════
static inline uint16_t processEffect(uint16_t in) {
  int16_t x = (int16_t)in - 512;   // 10-bit unsigned -> signed, centred at 0
  int16_t y = x;

  switch (P.effect) {

    // ── 1. Overdrive ────────────────────────────────────────────────────
    // Pre-amplify then hard-clip at full scale. thresh/16 is the gain factor:
    // thresh=16 -> 1x (just at breakup), thresh=180 -> 11x (rock/metal),
    // thresh=480 -> 30x (extreme saturation, near square wave).
    case FX_OVERDRIVE: {
      int32_t driven = (int32_t)x * P.thresh >> 4;
      if      (driven > S_MAX) { y = S_MAX; g_clip = 1; }
      else if (driven < S_MIN) { y = S_MIN; g_clip = 1; }
      else                       y = (int16_t)driven;
      break;
    }

    // ── 2. Delay ────────────────────────────────────────────────────────
    // Circular-buffer echo. Buffer stores input + feedback*echo;
    // output mixes dry + mix*echo.
    case FX_DELAY: {
      uint16_t dlen = P.delayLen;
      int16_t echo  = (int16_t)audioBuf[(wIdx - dlen) & BUF_MASK] << 2;

      int32_t outv  = (int32_t)x + (((int32_t)echo * P.mix)      >> 8);
      int32_t store = (int32_t)x + (((int32_t)echo * P.feedback)  >> 8);
      if (store > S_MAX) store = S_MAX;
      if (store < S_MIN) store = S_MIN;

      audioBuf[wIdx] = (int8_t)(store >> 2);
      wIdx = (wIdx + 1) & BUF_MASK;

      if (outv > S_MAX) outv = S_MAX;
      if (outv < S_MIN) outv = S_MIN;
      y = (int16_t)outv;
      break;
    }

    // ── 3. Chorus ───────────────────────────────────────────────────────
    // Triangle LFO sweeps the read tap between 48 and (48+depth) samples
    // behind the write head. Dry and wet mixed 50/50; no feedback path.
    case FX_CHORUS: {
      uint8_t tri = (lfoPhase < 32768u)
                    ? (uint8_t)(lfoPhase >> 7)
                    : (uint8_t)((65535u - lfoPhase) >> 7);
      lfoPhase += P.rate;

      uint16_t tapDist = 48u + (((uint16_t)tri * P.depth) >> 8);
      int16_t wet = (int16_t)audioBuf[(wIdx - tapDist) & BUF_MASK] << 2;

      audioBuf[wIdx] = (int8_t)(x >> 2);
      wIdx = (wIdx + 1) & BUF_MASK;

      y = (x >> 1) + (wet >> 1);
      break;
    }

    // ── 4. Reverb ───────────────────────────────────────────────────────
    // Ten equal-weight taps spanning 7.6–50.7 ms at 9615 Hz.
    // Equal weights (each 1/8, computed as sum>>3) create a dense reflection
    // pattern rather than 5 discrete echoes — this is what makes it sound
    // like reverb instead of EQ coloring.
    // Stability: loop gain = 10 * (1/8) * feedback/256 < 1 → feedback < 205.
    // Default feedback=190 gives ~300 ms half-life (medium room).
    case FX_REVERB: {
      int16_t t1  = (int16_t)audioBuf[(wIdx -  73u) & BUF_MASK] << 2;
      int16_t t2  = (int16_t)audioBuf[(wIdx -  97u) & BUF_MASK] << 2;
      int16_t t3  = (int16_t)audioBuf[(wIdx - 127u) & BUF_MASK] << 2;
      int16_t t4  = (int16_t)audioBuf[(wIdx - 163u) & BUF_MASK] << 2;
      int16_t t5  = (int16_t)audioBuf[(wIdx - 211u) & BUF_MASK] << 2;
      int16_t t6  = (int16_t)audioBuf[(wIdx - 271u) & BUF_MASK] << 2;
      int16_t t7  = (int16_t)audioBuf[(wIdx - 337u) & BUF_MASK] << 2;
      int16_t t8  = (int16_t)audioBuf[(wIdx - 397u) & BUF_MASK] << 2;
      int16_t t9  = (int16_t)audioBuf[(wIdx - 457u) & BUF_MASK] << 2;
      int16_t t10 = (int16_t)audioBuf[(wIdx - 487u) & BUF_MASK] << 2;
      int16_t rev = (int16_t)(
        ((int32_t)t1+t2+t3+t4+t5+t6+t7+t8+t9+t10) >> 3);

      int32_t store = (int32_t)x + (((int32_t)rev * P.feedback) >> 8);
      if (store > S_MAX) store = S_MAX;
      if (store < S_MIN) store = S_MIN;
      audioBuf[wIdx] = (int8_t)(store >> 2);
      wIdx = (wIdx + 1) & BUF_MASK;

      int32_t outv = (int32_t)x + (((int32_t)rev * P.mix) >> 8);
      if (outv > S_MAX) outv = S_MAX;
      if (outv < S_MIN) outv = S_MIN;
      y = (int16_t)outv;
      break;
    }

    // ── 5. Tuner ──────────────────────────────────────────────────────────
    // Audible output is clean passthrough (y = x); meanwhile the raw signal is
    // logged into the ring buffer so loop() can run AMDF pitch detection on it.
    case FX_TUNER: {
      audioBuf[wIdx] = (int8_t)(x >> 2);
      wIdx = (wIdx + 1) & BUF_MASK;
      // y stays = x (clean)
      break;
    }
  }

  // Track post-effect peak so AGC responds to what the listener actually hears
  int16_t ay = (y < 0) ? -y : y;
  if (ay > g_peak) g_peak = ay;

  int16_t out = y + 512;
  if (out > 1023) out = 1023;
  if (out < 0)    out = 0;
  return (uint16_t)out;
}

// ═══════════════════════════════════════════════════════════════════════════
//  setup
// ═══════════════════════════════════════════════════════════════════════════
void setup() {
  pinMode(A0, INPUT);
  pinMode(10, OUTPUT);   // audio PWM out (OC1B)
  pinMode( 9, OUTPUT);   // VGA PWM out   (OC1A)

  Serial.begin(115200);
  Serial.println(F("SF4 DSP v2  [0=clean 1=overdrive 2=delay 3=chorus 4=reverb 5=tuner]"));
  Serial.println(F("  e<0-5>    select effect           x         bypass"));
  Serial.println(F("  c<16-511> overdrive drive          v<0|1>    auto-VGA"));
  Serial.println(F("  d<1-512>  delay samples           g<0-255>  manual gain"));
  Serial.println(F("  f<0-255>  feedback / decay"));
  Serial.println(F("  m<0-255>  wet mix"));
  Serial.println(F("  r<1-48>   chorus depth (samples)"));
  Serial.println(F("  s<1-20>   chorus LFO rate"));
  Serial.println(F("  P,e,drv,dl,fb,mix,dp,rt,av,gain  atomic set-all (gain<0=keep)"));
  Serial.println(F("Telemetry: T,effect,peak,vga,clip,rxErr,freqDeciHz (freq in tuner mode)"));

  // ADC: free-running on A0, interrupt on completion, prescaler 128 -> ~9.6 kHz
  ADMUX  = (1 << REFS0);
  ADCSRB = 0;
  DIDR0  = (1 << ADC0D);
  ADCSRA = (1 << ADEN) | (1 << ADATE) | (1 << ADIE)
         | (1 << ADPS2) | (1 << ADPS1) | (1 << ADPS0)
         | (1 << ADSC);

  // Timer1: Mode 5 (8-bit Fast PWM), no prescaler -> 62.5 kHz carrier
  TCCR1A = (1 << COM1A1) | (1 << COM1B1) | (1 << WGM10);
  TCCR1B = (1 << WGM12)  | (1 << CS10);
  OCR1B  = 128;
  OCR1A  =  20;
  TIMSK1 =   0;
}

// ═══════════════════════════════════════════════════════════════════════════
//  Command handler
// ═══════════════════════════════════════════════════════════════════════════
static void handleCmd(char cmd, const char *arg) {
  long v = atol(arg);
  switch (cmd) {

    case 'e': {
      uint8_t fx = (uint8_t)constrain(v, FX_CLEAN, FX_TUNER);
      noInterrupts();
      memset(audioBuf, 0, sizeof(audioBuf));
      wIdx = 0; lfoPhase = 0;
      P.effect = fx;
      interrupts();
      Serial.print(F(">> effect   = ")); Serial.println(fx);
      break;
    }
    case 'c':
      noInterrupts(); P.thresh   = (int16_t)constrain(v, 1, 511);       interrupts();
      Serial.print(F(">> thresh   = ")); Serial.println(P.thresh);   break;
    case 'd':
      noInterrupts(); P.delayLen = (uint16_t)constrain(v, 1, BUF_SIZE); interrupts();
      Serial.print(F(">> delayLen = ")); Serial.println(P.delayLen); break;
    case 'f':
      noInterrupts(); P.feedback = (uint8_t)constrain(v, 0, 255);       interrupts();
      Serial.print(F(">> feedback = ")); Serial.println(P.feedback); break;
    case 'm':
      noInterrupts(); P.mix      = (uint8_t)constrain(v, 0, 255);       interrupts();
      Serial.print(F(">> mix      = ")); Serial.println(P.mix);      break;
    case 'r':
      noInterrupts(); P.depth    = (uint8_t)constrain(v, 1, 48);        interrupts();
      Serial.print(F(">> depth    = ")); Serial.println(P.depth);    break;
    case 's':
      noInterrupts(); P.rate     = (uint8_t)constrain(v, 1, 20);        interrupts();
      Serial.print(F(">> rate     = ")); Serial.println(P.rate);     break;
    case 'v':
      g_autoVGA = (v != 0);
      Serial.print(F(">> autoVGA  = ")); Serial.println(g_autoVGA ? F("ON") : F("OFF")); break;
    case 'g':
      OCR1A = (uint8_t)constrain(v, 0, 255);
      g_autoVGA = false;
      Serial.print(F(">> VGA gain = ")); Serial.println(OCR1A);     break;
    case 'x':
      noInterrupts();
      memset(audioBuf, 0, sizeof(audioBuf));
      wIdx = 0; lfoPhase = 0;
      P.effect = FX_CLEAN;
      interrupts();
      Serial.println(F(">> bypass (clean)"));                         break;

    // ── Atomic set-all frame (host link) ─────────────────────────────────
    // P,<effect>,<drive>,<delayLen>,<feedback>,<mix>,<depth>,<rate>,<autoVGA>,<gain>
    // Applies the whole parameter bank in one cli/sei section so the ISR never
    // reads a half-updated mix of old + new values. gain < 0 leaves the VGA
    // (and auto-VGA mode) untouched; gain >= 0 sets manual gain + auto-VGA off.
    case 'P': {
      int e, drv, dl, fb, mx, dp, rt, av, gn;
      if (sscanf(arg, ",%d,%d,%d,%d,%d,%d,%d,%d,%d",
                 &e, &drv, &dl, &fb, &mx, &dp, &rt, &av, &gn) != 9) {
        g_rxErr++;
        break;
      }
      uint8_t  fx       = (uint8_t)constrain(e,   FX_CLEAN, FX_TUNER);
      int16_t  thresh   = (int16_t)constrain(drv, 1, 511);
      uint16_t delayLen = (uint16_t)constrain(dl, 1, BUF_SIZE);
      uint8_t  feedback = (uint8_t)constrain(fb,  0, 255);
      uint8_t  mix      = (uint8_t)constrain(mx,  0, 255);
      uint8_t  depth    = (uint8_t)constrain(dp,  1, 48);
      uint8_t  rate     = (uint8_t)constrain(rt,  1, 20);

      noInterrupts();
      memset(audioBuf, 0, sizeof(audioBuf));   // effect may change → clear history
      wIdx = 0; lfoPhase = 0;
      P.effect   = fx;
      P.thresh   = thresh;
      P.delayLen = delayLen;
      P.feedback = feedback;
      P.mix      = mix;
      P.depth    = depth;
      P.rate     = rate;
      interrupts();

      if (gn >= 0) {                            // explicit manual gain
        OCR1A = (uint8_t)constrain(gn, 0, 255);
        g_autoVGA = false;
      } else {                                  // -1 sentinel: honour autoVGA flag
        g_autoVGA = (av != 0);
      }
      Serial.print(F(">> set effect=")); Serial.print(fx);
      Serial.print(F(" drive="));        Serial.print(thresh);
      Serial.print(F(" autoVGA="));      Serial.println(g_autoVGA ? F("ON") : F("OFF"));
      break;
    }

    default:
      g_rxErr++;
      break;
  }
}

// ═══════════════════════════════════════════════════════════════════════════
//  Tuner — AMDF pitch detection (runs in loop(), never the ISR)
// ═══════════════════════════════════════════════════════════════════════════
//  D(tau) = sum_{n=0..WIN-1} | buf[i-n] - buf[i-n-tau] |  is minimised over the
//  guitar lag range. The deepest dip is the fundamental period; parabolic
//  interpolation around it recovers sub-sample resolution (essential for the
//  high strings, where one whole-sample step is tens of cents at FS 9615 Hz).
#define TUNER_TAU_MIN  24     // ~400 Hz upper search bound
#define TUNER_TAU_MAX  128    // ~75 Hz lower search bound
#define TUNER_WIN      256    // comparison window length in samples
#define TUNER_SPAN    (TUNER_WIN + TUNER_TAU_MAX)  // samples the AMDF reaches back
#define TUNER_NOISE    12     // post-effect peak below this = treat as silence
#define FS_HZ          9615.0f

// The detector works on a frozen copy of the most recent TUNER_SPAN samples.
// Copying out of the live ring first is essential: the ISR keeps writing at
// ~9.6 kHz, so an in-place AMDF (tens of ms) would read samples that get
// overwritten mid-computation and smear the result.
static int8_t tunerSnap[TUNER_SPAN];   // tunerSnap[0] = newest, [k] = k samples older

// AMDF for one lag over the frozen snapshot (plain linear indexing).
static uint32_t amdf(uint16_t tau) {
  uint32_t d = 0;
  for (uint16_t n = 0; n < TUNER_WIN; n++) {
    int16_t diff = (int16_t)tunerSnap[n] - (int16_t)tunerSnap[n + tau];
    d += (diff < 0) ? (uint16_t)(-diff) : (uint16_t)diff;
  }
  return d;
}

static void detectPitch() {
  noInterrupts();
  int16_t peak = g_peak;
  interrupts();
  if (peak < TUNER_NOISE) { g_freqDeciHz = 0; return; }   // nothing plucked

  // Freeze the window: copy newest-first from the ring. ~384 byte reads finish
  // in well under one sample period of drift, so the snapshot is coherent.
  uint16_t i = wIdx;
  for (uint16_t k = 0; k < TUNER_SPAN; k++)
    tunerSnap[k] = audioBuf[(uint16_t)(i - 1 - k) & BUF_MASK];

  uint32_t bestD = 0xFFFFFFFFUL, sumD = 0;
  uint16_t bestTau = 0, count = 0;

  for (uint16_t tau = TUNER_TAU_MIN; tau <= TUNER_TAU_MAX; tau++, count++) {
    uint32_t d = amdf(tau);
    sumD += d;
    if (d < bestD) { bestD = d; bestTau = tau; }
  }

  // Reject if the dip isn't clearly below the mean (unvoiced / noisy), or if it
  // landed on a search boundary (can't interpolate / likely out of range).
  uint32_t mean = sumD / count;
  if (bestD * 2 > mean || bestTau <= TUNER_TAU_MIN || bestTau >= TUNER_TAU_MAX) {
    g_freqDeciHz = 0;
    return;
  }

  // Parabolic interpolation around the minimum for a sub-sample period.
  float d0 = (float)amdf(bestTau - 1);
  float d1 = (float)bestD;
  float d2 = (float)amdf(bestTau + 1);
  float denom = d0 - 2.0f * d1 + d2;
  float delta = (denom > 0.0f) ? 0.5f * (d0 - d2) / denom : 0.0f;
  float tauR  = (float)bestTau + delta;

  float f = FS_HZ / tauR;
  g_freqDeciHz = (uint16_t)(f * 10.0f + 0.5f);
}

// ═══════════════════════════════════════════════════════════════════════════
//  Main loop — serial parser + VGA
// ═══════════════════════════════════════════════════════════════════════════
void loop() {
  static char    line[48];   // wide enough for the atomic 'P' set-all frame
  static uint8_t llen = 0;

  // Serial command parser
  while (Serial.available()) {
    char ch = (char)Serial.read();
    if (ch == '\n' || ch == '\r') {
      if (llen > 0) {
        line[llen] = '\0';
        char *p = line;
        while (*p == ' ') p++;
        if (*p) handleCmd(*p, p + 1);
        llen = 0;
      }
    } else if (llen < (uint8_t)(sizeof(line) - 1)) {
      line[llen++] = ch;
    }
  }

  uint32_t now = millis();
  static uint32_t lastVGA   = 0;
  static uint32_t lastTelem = 0;
  static uint32_t lastTuner = 0;
  static int16_t  telemPeak = 0;

  // ── Tuner pitch detection (every 150 ms, tuner mode only) ───────────────
  if (P.effect == FX_TUNER) {
    if (now - lastTuner >= 150) { lastTuner = now; detectPitch(); }
  } else {
    g_freqDeciHz = 0;
  }

  // ── VGA loop (every 15 ms) ──────────────────────────────────────────────
  // One OCR1A step per tick: smooth gain rides with no pumping.
  // Noise floor guard prevents boosting silence into audible hiss.
  if (now - lastVGA >= 15) {
    lastVGA = now;

    noInterrupts();
    int16_t peak = g_peak;
    g_peak = 0;
    interrupts();

    if (peak > telemPeak) telemPeak = peak;

    if (g_autoVGA) {
      const int16_t VGA_HIGH  = 380;   // reduce gain above this peak
      const int16_t VGA_LOW   =  40;   // boost gain below this peak
      const int16_t VGA_NOISE =   8;   // silence floor — never boost below
      const uint8_t VGA_DEF   =  20;   // resting OCR1A (sweet-spot gain)
      const uint8_t VGA_MAX   =  80;   // max attenuation ceiling

      if (peak > VGA_HIGH) {
        if (OCR1A < VGA_MAX) OCR1A++;          // too loud  → step gain down
      } else if (peak > VGA_NOISE && peak < VGA_LOW) {
        if (OCR1A > 0)       OCR1A--;          // too quiet → step gain up
      } else {
        if      (OCR1A > VGA_DEF) OCR1A--;     // in range / silent → drift to resting
        else if (OCR1A < VGA_DEF) OCR1A++;
      }
    }
  }

  // ── Telemetry (every 100 ms) ────────────────────────────────────────────
  if (now - lastTelem >= 100) {
    lastTelem = now;
    uint8_t  clip;
    uint16_t freq;
    noInterrupts(); clip = g_clip; g_clip = 0; freq = g_freqDeciHz; interrupts();

    Serial.print(F("T,")); Serial.print(P.effect);
    Serial.print(',');      Serial.print(telemPeak);
    Serial.print(',');      Serial.print(OCR1A);
    Serial.print(',');      Serial.print(clip);
    Serial.print(',');      Serial.print(g_rxErr);
    Serial.print(',');      Serial.println(freq);

    telemPeak = 0;
  }
}

// ═══════════════════════════════════════════════════════════════════════════
//  ADC ISR — fires at ~9.6 kHz
// ═══════════════════════════════════════════════════════════════════════════
ISR(ADC_vect) {
  OCR1B = (uint8_t)(processEffect(ADC) >> 2);
}

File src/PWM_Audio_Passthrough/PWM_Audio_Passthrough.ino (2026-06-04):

/*
 * Arduino Uno R3 — 8-bit PWM audio output (passthrough) + optocoupler control
 *
 * INPUT : guitar signal biased to 2.5 V, swinging 0–5 V  -> A0
 *         ADC reads 0..1023, where 512 ≈ 2.5 V = silence.
 *
 * OUTPUTS (both on Timer1, 8-bit Fast PWM, carrier = 62500 Hz):
 *   AUDIO       -> pin 10 (OC1B) -> low-pass filter -> audio out
 *   OPTOCOUPLER -> pin 9  (OC1A) -> RC -> DC -> LED in the VGA gain stage
 *
 * WHY 62.5 kHz (8-bit) AND NOT 15.6 kHz (10-bit)?
 *   Guitar tone needs audio out to ~5 kHz (harmonics). At a 15.6 kHz carrier
 *   the carrier is only ~3x above the audio, so NO filter can pass 5 kHz while
 *   rejecting the carrier — you're forced to choose ripple OR dull tone.
 *   Pushing the carrier to 62.5 kHz puts it ~12x above the audio, so a gentle
 *   filter at fc ≈ 5 kHz covers the full guitar range AND kills the carrier.
 *   Trade-off: 8-bit = 256 levels instead of 1024 (≈48 dB SNR, fine for guitar).
 *
 * RECOMMENDED ANALOG OUTPUT CHAIN (matches the build notes):
 *   LOW-PASS (sets top of band, kills carrier) — two passive RC + LM358 buffer:
 *     pin 10 ─R1(2.2k)─┬─→(+)LM358 buf─out─R2(2.2k)─┬─→ C8
 *                     C1(15nF)                      C2(15nF)
 *                      │                             │
 *                     GND                           GND     (each fc ≈ 4.8 kHz)
 *   HIGH-PASS (sets bottom of band, strips 2.5 V bias) — C8 + R13:
 *     ...─┬─ C8(10uF) ─┬─→ audio jack
 *         │           R13(100k)
 *         │            │
 *        node B       GND                           (fc ≈ 0.16 Hz, no bass loss)
 *   NOTE: do NOT use a Sallen-Key around the LM358 — the LM358 is too slow
 *         (~1 MHz GBW) and the topology leaks the carrier through Ca. Use the
 *         passive RC + buffer chain above instead.
 *
 * KEY POINT: OC1A = pin 9, OC1B = pin 10. They are two INDEPENDENT compare
 *            outputs of the same timer, so audio (OCR1B) and the optocoupler
 *            (OCR1A) coexist without fighting. Both run the full 0..255 range
 *            — do NOT use analogWrite() here (it assumes the core's default
 *            8-bit timer config, which we have replaced).
 *
 * TIMING: Timer1 overflow ISR = sample tick = 16 MHz / 256 = 62500 Hz.
 *         (Effective audio sample rate is set by the free-running ADC at
 *          ~19 kHz; the PWM just refreshes faster than that, which is fine.)
 */

void setup() {
  pinMode(A0, INPUT);   // audio input
  pinMode(10, OUTPUT);  // audio PWM out (OC1B)
  pinMode(9,  OUTPUT);  // optocoupler PWM out (OC1A)

  Serial.begin(9600);
  Serial.println("--- Optocoupler Interactive Terminal ---");
  Serial.println("Type a gain value 0..255 and hit Enter.");
  Serial.println("0   = LED Off (Max LDR resistance)");
  Serial.println("255 = LED Max (Min LDR resistance)");
  Serial.println("----------------------------------------");

  // ---- ADC: free-running so a fresh sample is always ready to read ----
  ADMUX  = (1 << REFS0);                  // AVcc (5 V) ref, right-adjusted, channel A0
  ADCSRB = 0;                             // free-running trigger source
  DIDR0  = (1 << ADC0D);                  // disable digital input buffer on A0 (less noise)
  ADCSRA = (1 << ADEN)                    // enable ADC
         | (1 << ADATE)                   // auto-trigger (free-running)
         | (1 << ADPS2) | (1 << ADPS1)    // prescaler /64 -> 250 kHz ADC clock (~19 kHz/sample)
         | (1 << ADSC);                   // start first conversion

  // ---- Timer1: Mode 5 = 8-bit Fast PWM (TOP = 0x00FF) on BOTH OC1A & OC1B ----
  TCCR1A = (1 << COM1A1)                  // non-inverting PWM on OC1A (pin 9, optocoupler)
         | (1 << COM1B1)                  // non-inverting PWM on OC1B (pin 10, audio)
         | (1 << WGM10);                  // WGM[11:10] = 01
  TCCR1B = (1 << WGM12)                   // WGM12 = 1  -> mode 5 (WGM[13:12] = 01)
         | (1 << CS10);                   // no prescale -> 16 MHz / 256 = 62500 Hz

  OCR1B  = 128;                           // audio: start mid-scale (2.5 V = silence)
  OCR1A  = 0;                             // optocoupler: LED off to start
  TIMSK1 = (1 << TOIE1);                  // overflow interrupt = our sample tick
}

void loop() {
  // Optocoupler gain control over serial (non-blocking; never stalls audio)
  if (Serial.available() > 0) {
    int value = Serial.parseInt();
    while (Serial.available() > 0) Serial.read();   // flush newline

    OCR1A = constrain(value, 0, 255);               // set LED brightness (full 8-bit)

    Serial.print(">> Optocoupler PWM set to: ");
    Serial.println(OCR1A);
  }
}

// Fires once per PWM cycle = 62500 Hz
ISR(TIMER1_OVF_vect) {
  uint16_t sample = ADC;        // latest 0..1023 reading (512 = 2.5 V bias)

  // ---- DSP goes here. Passthrough for now: ----
  // sample = processEffect(sample);

  OCR1B = sample >> 2;          // scale 10-bit ADC -> 8-bit PWM (512 -> 128 = mid)
}

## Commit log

2026-05-25 output stage simulation
2026-06-06 audio output stage edited
    [SF4.kicad_sch]
2026-06-06 updated schematic for the output stage
    [SF4.kicad_sch]
2026-06-08 feat(web): rebuild dashboard in React + Vite; drop MODEL DSP-1; add clear 'no device connected' state
